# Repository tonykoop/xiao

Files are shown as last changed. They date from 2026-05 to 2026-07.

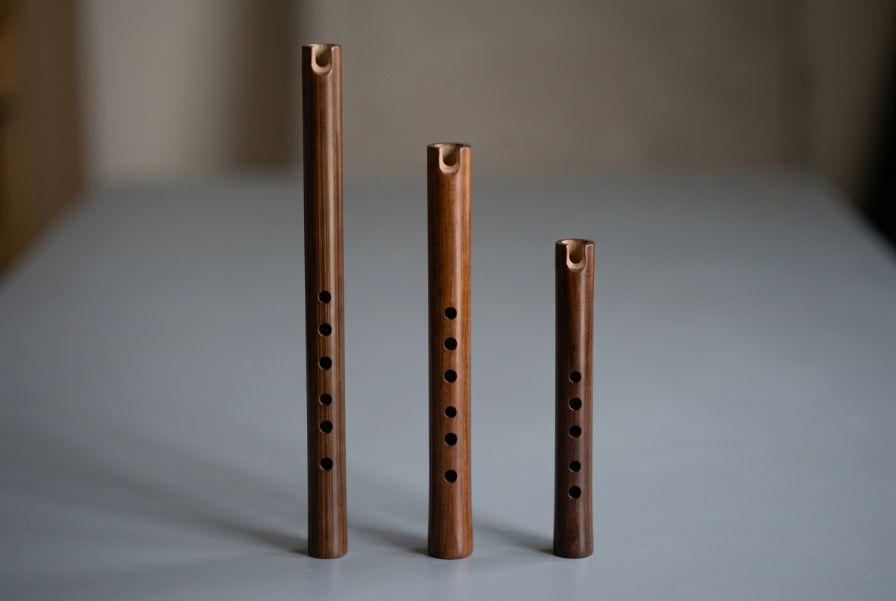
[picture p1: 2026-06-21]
images/family-group.png

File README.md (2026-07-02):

# Xiao Family (箫)

*Engineering documentation and parametric design for the xiao — Chinese end-blown vertical bamboo flute.*

**Build ID:** XIAO-001 · **Variants:** Bei Xiao · Nan Xiao · Qin Xiao · **Scale:** 8-hole chromatic  
**Prototype target:** G Nan Xiao (root D4) · Black walnut · Headstock-driven deep-bore drilling  
Part of the [tonykoop/instrument-maker](https://github.com/tonykoop/instrument-maker) catalogue.

**Status:** L2 V5 build-packet candidate. Bore lengths and tone-hole positions are first-order model predictions — all tuning claims are estimates and must be validated on prototype. All SVGs in `drawings/` are derived previews; Wolfram sources are present but runtime execution is not yet recorded.

---

<!-- hero image placeholder: replace with finished instrument photo after build. Current L2 packet uses generated technical drawings as visual evidence. -->
Xiao bore profile

---

## What this is

The xiao (箫, *xiāo*) is a Chinese end-blown vertical flute with a breathy, dark tone — one of the oldest and most meditative instruments in the Chinese tradition. This repo contains a complete engineering build packet for a CNC-turned wooden prototype across three bore variants:

- **Bei Xiao (北箫)** — Northern style, capped U-notch, larger bore
- **Nan Xiao (南箫)** — Southern style, open bamboo-root end (most common; prototype target)
- **Qin Xiao (琴箫)** — Narrow-bore companion to the guqin zither

The design table covers 26 keys from C4 through D6. The G Nan Xiao (root D4, bore ≈ 22 mm) is the prototype focus.

The key engineering challenge is the 22.5 in straight bore — drilled before turning the exterior, using the headstock-driven technique so the bore axis becomes the lathe datum.

---

## File Map

| File / Folder | Description |
|---|---|
| `xiao-design-table.xlsx` | Parametric design table — all 26 keys × 3 variants |
| `design.md` | Governing acoustic model, hole positions, formulas, assumptions |
| `bom.csv` | Bill of materials |
| `sourcing.csv` | Supplier table |
| `cut-list.csv` | Stock and cut dimensions |
| `validation.csv` | Tuning checkpoints with pass/fail blanks |
| `assembly-manual.md` | Stage-by-stage build instructions |
| `supplier-rfq.md` | RFQ templates for lumber and tooling |
| `visual-bom-brief.md` | Photo/image layout spec for the visual BOM |
| `drawing-brief.md` | Drawing specifications and critical dimensions |
| `risks.md` | Red-team risk register — 12 risks with verification tests |
| `resources.md` | Cultural provenance, acoustic references, open review items |
| `jig-decision.md` | Fixture selection decisions for bore drilling and tone holes |
| `photo-shotlist.md` | Staged photo list for build documentation |
| `drawings/` | Dimensioned SVG drawings (bore profile, tone holes, embouchure, drill setup) |
| `cnc/` | Operation graph, operations.csv, setup-sheet.md |
| `jigs/` | Jig specs — headstock bore carrier, tonehole V-block |
| `wolfram/instrument-model.wl` | Wolfram acoustic model package |
| `cad/` | Parametric OpenSCAD master (`cad/xiao.scad`, bore + tone-hole array) plus SolidWorks CAD placeholder |
| `evolution/` | Evolution-pipeline Stage 0 intake — design intent, revision register, CAD master manifest (Gate A not yet run) |
| `site/index.html` | Build-log static site |
| `images/` | Build photos (populate during build) |
| `data/` | Design intake JSON and CSV |

---

## Build Workflow

```
Design table → Acoustic model → Stock prep → Bore scrap blank (validate) →
Bore tonewood → Turn OD from bore axis → Cut embouchure notch →
Lay out tone holes → Drill tone holes → Voice / tune → Finish → Validate
```

**Critical rule: bore before turning.** The bore axis becomes the lathe datum. Do not turn the exterior first.

---

## Acoustic Model (summary)

- **Model:** Open-open cylindrical pipe — `f = c / (2 · L_eff)`
- **Speed of sound:** 13,504 in/s at 68°F
- **G Nan Xiao prototype:** root D4 = 293.66 Hz → L_eff = 22.99 in → L_bore = 22.47 in
- **End correction (each open end):** δ = 0.6 × r = 0.260 in (embouchure assumed open — TBD)
- **Tone holes:** 8-hole chromatic, offsets +2,+3,+4,+5,+7,+9,+10,+11 semitones from root
- **NAF corrections do NOT apply.** All hole positions first-order until prototype measured.

See `design.md` for full model, all formulas, and the complete hole position table.

---

## Key Drawings

| Drawing | File |
|---|---|
| Bore profile (section view) | `drawings/xiao-bore-profile.svg` |
| Tone hole layout (plan view) | `drawings/xiao-tonehole-layout.svg` |
| Embouchure notch detail | `drawings/xiao-embouchure-detail.svg` |
| Headstock drilling setup | `drawings/xiao-headstock-drill-setup.svg` |

---

## Build Risks (top 3)

1. **RISK-S01 — Bore wander (HIGH):** 22.5 in bore wander risks thin wall or structural failure. Validate on scrap blank first; reject if wander > 0.030 in.
2. **RISK-A01 — Embouchure end correction (HIGH):** Model assumes δ_emb = 0.260 in. Real value unknown until prototype. Leave trim allowance and measure before drilling holes.
3. **RISK-S02 — Embouchure notch cracks (HIGH):** U-notch stress concentration at wall. Radius corners; seal grain immediately. Full register in `risks.md`.

---

## License

[CC BY 4.0](LICENSE) — see LICENSE for details.

---

*Heifer Zephyr instrument catalogue · [tonykoop](https://github.com/tonykoop)*

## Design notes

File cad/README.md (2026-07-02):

# Xiao — CAD Folder

**Status:** `cad/xiao.scad` — parametric OpenSCAD master (bore + tone-hole array only; blowing-edge notch out of scope) — added 2026-07-01. Authority: `pending_measurement`; not fabrication authority until reviewed against a measured prototype. See `mcp-session-log.md` for provenance. SolidWorks parts below remain planned/TBD.

## Planned files

| File | Description | Status |
|---|---|---|
| `xiao-body-nan.SLDPRT` | SolidWorks part — Nan Xiao body (G key) | TBD |
| `xiao-body-bei.SLDPRT` | SolidWorks part — Bei Xiao body | TBD |
| `xiao-body-qin.SLDPRT` | SolidWorks part — Qin Xiao body | TBD |
| `xiao-foot-plug.SLDPRT` | Foot plug part | TBD |
| `xiao-assembly.SLDASM` | Full assembly with plug | TBD |
| `sw-design-table.xlsx` | SolidWorks design table generated from xiao-design-table.xlsx | TBD |

## Workflow

1. Generate SW design table: `python3 scripts/generate_sw_design_table.py . --output cad/sw-design-table.xlsx --part-name XIAO-001_NanXiao`
2. Create SolidWorks part from bore and OD dimensions in design.md
3. Drive all dimensions from the design table (bore ID, OD, wall, total length, hole positions)
4. Export STEP/STL for reference if needed

See `references/solidworks-integration.md` for Tony's SolidWorks workflow conventions.

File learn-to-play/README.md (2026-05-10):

# learn-to-play / Xiao (D)

Starter songbook for the **D-tuned xiao** (洞箫) from the [`xiao`](https://github.com/tonykoop/xiao) build packet. Generated by the [`sheet-music`](https://github.com/tonykoop/sheet-music) skill.

The xiao is a vertical end-blown bamboo flute. The tone is breathy and deep; it favours slow, expressive playing.

Range: **D4 – D6** (two octaves). 6 finger holes + 1 thumb hole.

## Folder map
| Folder | Contents |
|---|---|
| `00-warmup-scales/` | D pentatonic range walk, interval study, vibrato exercise |
| `01-easy/` | Three classic Chinese traditional melodies |
| `02-intermediate/` | Two longer pieces with wider range |
| `03-original/` | *Dawn Reed Song* — Heifer Zephyr original |
| `fingering-charts.svg` | D major and D pentatonic fingering chart, D4–D6 |

## Repertoire

### 01-easy
| Tune | Tradition |
|---|---|
| Mo Li Hua (Jasmine Flower) | Trad Chinese folk song (pre-1900) |
| Xiao He Cai Lian (Picking Lotus) | Trad Chinese (Tang Dynasty tradition) |
| Hotaru Koi (Come Firefly) | Trad Japanese folk (pre-1900) |

### 02-intermediate
| Tune | Tradition |
|---|---|
| Gao Shan Qing (High Mountain Trail) | Trad Taiwanese / Hokkien (pre-1929) |
| Feng Yang Hua Gu (Flower Drum Song) | Trad Chinese (Ming Dynasty origin) |

### 03-original
**Dawn Reed Song** — 24-bar through-composed, D minor pentatonic, ♩=52.

## Notes on xiao notation
Standard staff notation uses concert pitch. The xiao has a low, dark tone; play the written notes
one octave lower than a flute reading the same score (an octave transposing instrument in practice,
though not formally). ABC files here are written for the player's reading convenience.

## License
Arrangements MIT-licensed by Tony Koop / Heifer Zephyr. Traditional tunes: PD.

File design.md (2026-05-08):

# Xiao Family — Design Document

**Instrument:** Xiao (箫) — Chinese end-blown vertical bamboo flute  
**Family variants:** Bei Xiao (北箫) · Nan Xiao (南箫) · Qin Xiao (琴箫)  
**Scale:** 8-hole chromatic  
**Build ID:** XIAO-001  
**Packet version:** v4.3 root-mode  
**Date:** 2026-05-08  
**Status:** First-order acoustic model. Tuning claims are estimates until prototype measured.

---

## 1. Design Intent

The xiao is one of the oldest Chinese wind instruments — an end-blown, notched-embouchure flute with a characteristically dark, breathy tone. This design packet targets a **G Nan Xiao** (root D4, bore ≈ 0.866 in / 22 mm) as the prototype instrument, with the parametric design table covering 26 keys and all three bore variants. The priority challenges are:

- Long-bore cylindrical drilling (≥ 22 in) without wander
- Accurate tone-hole placement from a first-order acoustic model, with tuning trim allowance baked in
- Embouchure geometry (U-notch vs V-notch) and its effect on attack, intonation, and octave response
- End corrections: both ends treated as open terminations (first-order); embouchure end correction is an assumption pending prototype measurement

CNC production is intended for wooden prototypes; bamboo and lacquered-bore variants are noted as material alternatives.

---

## 2. Governing Acoustic Model

### 2.1 Model choice

The xiao is an **open-open cylindrical pipe** (open at embouchure end, open at foot). Use the open-open pipe model:

```
f = c / (2 · L_eff)
L_eff = c / (2 · f)
```

- `c` = speed of sound = 331.3 × √(1 + T_C / 273.15) m/s  
  At 68°F (20°C): **c = 343.0 m/s = 13,504 in/s**

**Do not apply NAF K2 corrections here.** Those corrections are derived from Tony's NAF bore-diameter data and do not apply to the xiao's different bore range, embouchure geometry, or playing technique. Mark all first-order predictions as estimates; add measured corrections to validation.csv after prototype testing.

### 2.2 End corrections

Each open termination adds approximately 0.6 × radius to the effective acoustic length:

```
δ_end ≈ 0.6 · r    (Levine-Schwinger approximation)
```

For an open-open pipe with two open ends:

```
L_eff = L_bore + 2 · δ_end = L_bore + 1.2 · r
```

**Embouchure-end assumption:** The U-notch embouchure is treated as an open end in this first-order model (δ_emb ≈ 0.6·r). In practice, the notch geometry, player lip coverage, and jet angle all modulate the effective length. Expect the embouchure end correction to require empirical refinement on the prototype. Flag this row in validation.csv.

**Foot-end correction:** Standard open-end correction applies at the foot (δ_foot = 0.6·r).

### 2.3 Prototype target — G Nan Xiao

| Parameter | Value | Source |
|---|---|---|
| Xiao key name | G (四孔 = G4) | Naming convention: 4th hole |
| Root note (all holes closed) | D4 | Key − 5 semitones |
| Root frequency | 293.66 Hz | f = 440 × 2^((62−69)/12) |
| Speed of sound | 13,504 in/s | 68°F, 0% RH (shop estimate) |
| **L_eff (acoustic length)** | **22.99 in** | c / (2 · 293.66) |
| Bore ID | 0.866 in | Nan Xiao design table |
| Bore radius | 0.433 in | Bore ID / 2 |
| End correction (each end) | 0.260 in | 0.6 × 0.433 |
| Total end correction | 0.520 in | 2 × δ_end |
| **L_bore (physical bore)** | **22.47 in** | L_eff − 0.520 |
| Wall thickness | 0.236 in | Design table |
| OD (bore + 2·wall) | 1.338 in | Bore + 2 × wall |
| Mouthpiece section length | 2.5 in | Design table (Nan Xiao) |
| **Total blank length** | **~25.5 in** | L_bore + mouthpiece + trim |

> **⚠ FIRST-ORDER ESTIMATE.** L_bore = 22.47 in is the model prediction with assumed end corrections. Add +0.25 in trim allowance to the blank. Final length determined by tuning measurement on the prototype.

### 2.4 Tone-hole placement (first-order)

Acoustic length method (open-open pipe, Benade first-order approximation):

```
d_from_foot(hole_n) = L_eff × (f_root / f_hole_n)
```

This gives the distance from the foot-end opening to where each tone hole's center should ideally be placed for a lossless open termination at that hole. Real-world corrections for finite hole size, undercutting, and adjacent-hole interaction are applied empirically during voicing.

**G Nan Xiao — 8 tone holes (first-order):**

| Hole | Finger | Note | MIDI | Freq (Hz) | Dist from foot (in) | Dist from foot (mm) |
|---|---|---|---|---|---|---|
| 1 | RH pinky | E4 | 64 | 329.63 | 20.48 | 520 |
| 2 | RH ring | F4 | 65 | 349.23 | 19.33 | 491 |
| 3 | RH middle | Gb4 | 66 | 369.99 | 18.25 | 464 |
| 4 | RH index | G4 | 67 | 392.00 | 17.22 | 437 |
| 5 | LH ring | A4 | 69 | 440.00 | 15.34 | 390 |
| 6 | LH middle | B4 | 71 | 493.88 | 13.67 | 347 |
| 7 | LH index | C5 | 72 | 523.25 | 12.90 | 328 |
| 8 | LH thumb | Db5 | 73 | 554.37 | 12.18 | 309 |

> **⚠ FIRST-ORDER ONLY.** These distances will shift in practice. Drill holes 1–2 mm closer to the foot than predicted (under-length tuning margin), then reposition by undercutting. Do not finalize positions without prototype measurement.

### 2.5 Scale offsets (xiao 8-hole chromatic)

From acoustic-models.md — verified against design table:

```
+2, +3, +4, +5, +7, +9, +10, +11 semitones from root
```

Notes +1, +6, +8 require cross-fingering or half-holing. Second octave by overblowing (overblow ratio ≈ 2:1 for cylindrical open pipe).

### 2.6 Naming convention

> **"G xiao"** means hole 4 produces G. Root (all holes closed) = G − 5 semitones = D.  
> Design table column: Root Note = D4 → Xiao Key Name = G4.

---

## 3. Bore Variants

Three bore families are covered in the design table. Prototype is **Nan Xiao**.

| Variant | Bore type | Bore ID range | Wall | Mouthpiece | Character |
|---|---|---|---|---|---|
| Bei Xiao (北箫) | Capped U-notch | 0.472–0.787 in | Proportional | 2.0 in | Northern; fuller tone, larger bore |
| Nan Xiao (南箫) | Open (bamboo root end) | 0.630–0.984 in | Proportional | 2.5 in | Southern; warm, breathy; most common |
| Qin Xiao (琴箫) | Capped U-notch (narrow) | 0.315–0.630 in | Proportional | 3.0 in | Narrow bore; refined tone for guqin pairing |

Blank width/thickness cells are marked TBD in the design table — to be filled once stock form (round rod, split-blank, or bamboo) is confirmed.

---

## 4. Material Assumptions

| Parameter | Prototype | Note |
|---|---|---|
| Body material | Black walnut or cherry | CNC-machinable hardwood. Bamboo (madake/zizhu) for traditional build |
| Bore treatment | TBD | Linseed oil, lacquer, or shellac; internal lacquer stabilizes bore and affects tuning |
| Stock form | Round rod or split-blank | See jig-decision.md for drilling method selection |
| Finish | Natural oil + wax | Avoid thick varnish on bore |

---

## 5. Key Assumptions & Open Questions

| Item | Assumption | Status |
|---|---|---|
| Embouchure end correction | 0.6·r (same as foot) | **TBD — measure on prototype** |
| Bore taper | Zero (cylindrical) | Bamboo is slightly tapered; wooden version is truly cylindrical |
| Hole diameter | TBD (traditional: ~8–10 mm for front holes) | Affects cutoff frequency and playability |
| Hole undercutting | TBD | Cross-cut and undercut during voicing |
| Internal lacquer effect | Assumed negligible | Lacquer shifts effective bore diameter; validate |
| Temperature at play | 68°F / 20°C | Tune at 68°F; note 1 cent/°F sensitivity |
| Breath pressure | Assumed constant | Overblowing model: pressure ratio ≈ 4:1 to 6:1 for second octave |

---

## 6. Parametric Formulas

All formulas should be reproduced parametrically in `xiao-design-table.xlsx`:

```
c = 13504 * SQRT(1 + T_F/491.67)          " in/s, T_F in Fahrenheit
f_root = 440 * 2^((MIDI_root - 69) / 12)  " root frequency
L_eff = c / (2 * f_root)                   " acoustic length, in
delta_end = 0.6 * (bore_ID / 2)            " end correction per end, in
L_bore = L_eff - 2 * delta_end             " physical bore length, in
dist_from_foot(n) = L_eff * (f_root / f_hole_n)  " tone hole position, in
f_hole_n = 440 * 2^((MIDI_root + offset_n - 69) / 12)  " hole frequency
```

Offsets: +2, +3, +4, +5, +7, +9, +10, +11 (holes 1–8).

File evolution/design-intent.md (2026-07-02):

# Design Intent — xiao rev A

- Master CAD: `cad/xiao.scad` (sha256: 3832be6631ce64d141e368377fbe873fe25e27d0db50bf8b6a6dd54874659363), driven by `xiao-design-table.xlsx` (sha256: 17c8b5783f117235e83f1da46e28202ae674b4700645ce71d5cdee196199d32a)
- Function: End-blown Chinese vertical bamboo flute (箫). The G Nan Xiao prototype (root D4, open-open cylindrical bore) is bored straight through a hardwood blank before the exterior is turned (bore axis = lathe datum), then cut with a U-notch embouchure at the top and 8 tone holes (7 front + 1 back thumb) drilled and voiced to a first-order acoustic model. Played near-vertical; breath jet against the notch edge excites the open-open pipe resonance. See design.md and README.md "What this is" / "Acoustic Model".
- Environment: hand-held wind instrument; breath moisture enters the bore during play, so bore finish and material stability (checking, cracking) matter. No sustained structural load beyond normal handling.
- Target qty: 1 (prototype). Deadline: TBD. Budget/unit ceiling: TBD.

## Critical dimensions (carry tolerances)

| Feature | Nominal | Tolerance | Why critical | Source |
| --- | --- | --- | --- | --- |
| Bore ID | 0.866 in | reject scrap-blank wander > 0.030 in (RISK-S01) | sets L_bore and all hole positions | design.md section 2.3 (worked Nan Xiao table); flagged discrepancy vs xiao-design-table.xlsx row16 col E = 0.984 in — see cad/xiao.scad header |
| Physical bore length (L_bore) | 22.47 in | +0.25 in trim allowance before final tuning cut | sets fundamental (D4 = 293.66 Hz) | design.md section 2.3, formula L_eff - 2*delta_end |
| Wall thickness | 0.236 in | min 0.118 in per RISK-S01 (Qin Xiao floor) | structural integrity of 22.5 in bore | design.md section 2.3; flagged discrepancy vs xlsx row17 col E = 0.276 in |
| Tone-hole positions (holes 1-8, dist. from foot) | 20.48 / 19.33 / 18.25 / 17.22 / 15.34 / 13.67 / 12.90 / 12.18 in | drill under-length 1-2 mm toward foot, correct by undercutting (measurement_required) | intonation of 8-hole chromatic scale | design.md section 2.4 (first-order acoustic-length method); reproduced by formula in cad/xiao.scad, exact match verified via OpenSCAD echo |
| Hole diameter | 0.354 in (9 mm) | TBD — affects cutoff frequency and playability | voicing | design.md section 5 "Key Assumptions" — explicitly TBD, traditional range ~8-10mm; used here as a documented ASSUMPTION, not a design-table value |
| Embouchure end correction | 0.260 in (0.6*r), applied as open-end assumption | TBD — measure on prototype (RISK-A01) | fundamental frequency accuracy | design.md section 2.2/2.3; NOT modeled as cut geometry in cad/xiao.scad (blowing edge out of scope) |
| Mouthpiece stock length | 2.5 in | n/a (uncut stock allowance) | leaves material for embouchure notch carving | design.md section 2.3 / xiao-design-table.xlsx row20 col E (both sources agree) |

## Incidental (free for DFM)

- Exterior turning profile/taper of the body (beyond the bore-driven OD), decorative wrap placement, foot-plug cosmetic shaping, finish sheen.

## Must-nots (DFM may never violate)

- Never turn the exterior before boring — the bore axis is the lathe datum (design.md "Build Workflow"; "Critical rule: bore before turning").
- Never exceed 0.030 in bore wander on the scrap-blank validation test before committing to the tonewood blank (RISK-S01, risks.md).
- Never cut the embouchure notch wider than the bore diameter (~12 mm max) or with square (non-radiused) corners — stress-concentration crack risk at the thin mouthpiece wall (RISK-S02, risks.md).
- Never drill tone holes before the embouchure cut and fundamental-frequency check — δ_emb must be measured and L_bore reconciled first, or all hole positions will be systematically off (RISK-A01, risks.md).
- Never apply bore finish after tone holes are drilled without masking — finish pooling in holes sharpens notes unpredictably (RISK-FF01, risks.md).

## Material intent

- Preferred: black walnut (or cherry) hardwood body blank, kiln-dried (MC <= 8%); bore finish boiled linseed oil or shellac; exterior finish Danish oil or wax. Per bom.csv.
- Acceptable subs: bamboo (madake/zizhu) for a traditional build, per design.md section 4 "Material Assumptions" — not costed in bom.csv.
- Forbidden: none recorded.

## Stage status

Stage 0 intake complete 2026-07-01. Gate A (Alpha shop compile) NOT yet run — no concessions logged, nothing presented as shippable.

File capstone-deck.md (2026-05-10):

# Xiao Family Capstone Deck Outline
## XIAO-001 · G Nan Xiao · v4.3 · 2026-05-08

> Binary .pptx: run `python3 scripts/generate_capstone_docs.py . --title "Xiao Capstone"` when bash is available.

---

# Slide 1 — Title

**Xiao Family (箫)**  
*Chinese End-Blown Vertical Flute — Engineering Documentation*  
Build ID: XIAO-001 · G Nan Xiao prototype · Heifer Zephyr · 2026-05-08

[hero image: finished xiao, vertical, natural light]

---

# Slide 2 — What This Project Is

**One sentence:** A parametric engineering study of the Chinese xiao, producing a CNC-turned wooden prototype of the G Nan Xiao with a 22.5 in deep-bored cylindrical bore, 8-hole chromatic scale, and first-order acoustic validation.

**Intended use:**
- Demonstrate long-bore woodwind design and headstock-driven drilling technique
- Establish baseline acoustic model for three bore variants (Bei/Nan/Qin)
- Populate the Heifer Zephyr instrument catalogue with a new woodwind family

**Design table covers:** 26 keys × 3 variants (Bei / Nan / Qin Xiao)

---

# Slide 3 — File Map

| File | Purpose | Use when |
|---|---|---|
| `xiao-design-table.xlsx` | Parametric design — all keys and variants | All dimensions |
| `design.md` | Acoustic model, formulas, hole positions | Building the physics |
| `assembly-manual.md` | Stage-by-stage build guide | In the shop |
| `cnc/setup-sheet.md` | Operation plan, release checks | Before each operation |
| `jigs/*.md` | Jig specs for bore and tone holes | Fixture setup |
| `drawings/*.svg` | Bore profile, tone holes, embouchure, drill setup | Layout and reference |
| `wolfram/instrument-model.wl` | Wolfram acoustic model package | Physics validation |
| `risks.md` | 12 risks with verification tests | Before cutting material |
| `validation.csv` | Tuning checkpoints | After each voicing pass |
| `site/index.html` | Public build-log site | Sharing with outside makers |

---

# Slide 4 — Build Workflow

```
Stock prep → Bore SCRAP (validate) → Bore tonewood → Turn OD from bore axis
→ Embouchure notch (by ear) → Lay out tone holes → Drill holes
→ Voice / tune (strobe) → Bore finish → Validate → Ship
```

**Critical rule: Bore before turning.** The bore axis is the lathe datum.  
**Critical rule: Scrap blank first.** Bore wander < 0.030 in before touching tonewood.  
**Critical rule: All tuning claims first-order** until prototype measured.

---

# Slide 5 — Acoustic Model

**Governing model:** Open-open cylindrical pipe  
`f = c / (2 · L_eff)` · `L_eff = L_bore + 1.2 · r` (both ends open)

**G Nan Xiao prototype:**

| Parameter | Value | Status |
|---|---|---|
| Root (D4) | 293.66 Hz | Formula |
| L_eff | 22.99 in | Calculated |
| δ_emb | 0.260 in assumed | **TBD — measure on prototype** |
| L_bore | 22.47 in | **FIRST-ORDER ESTIMATE** |
| Bore ID | 0.866 in | Design table |

**Scale:** 8-hole chromatic, offsets +2,+3,+4,+5,+7,+9,+10,+11 from root  
**Key convention:** Xiao key = 4th hole note (G xiao has root D)  
**No NAF corrections** — different embouchure geometry and bore range.

[embed: drawings/xiao-tonehole-layout.svg]

---

# Slide 6 — BOM and Sourcing

| Item | Qty | Cost | Status |
|---|---|---|---|
| Black walnut blank 1.5×1.5×26 in | 1 | $8–15 | TBD |
| Scrap pine/poplar blank | 1 | $3–5 | TBD |
| 1/4 in pilot bit 18 in+ | 1 | $8 | TBD |
| 55/64 in finish bit 18 in+ | 1 | $25–45 | **Order first — lead time 3–5 days** |
| 7/8 in adjustable reamer | 1 | $35 | TBD |
| Bore + exterior finish | 1 set | $9 | Available |
| Tailstock carrier (shop-made) | 1 | $15 | TBD |
| **Total (est.)** | | **~$109** | |

**Lead-time risk:** 55/64 in bit. Order before cutting stock.

---

# Slide 7 — Drawings and CAD

[embed: drawings/xiao-bore-profile.svg] — Bore Profile (DWG-001)  
[embed: drawings/xiao-headstock-drill-setup.svg] — Drill Setup (DWG-004)

| Drawing | Status | File |
|---|---|---|
| Bore profile | ✅ Generated | drawings/xiao-bore-profile.svg |
| Tone hole layout | ✅ Generated | drawings/xiao-tonehole-layout.svg |
| Embouchure detail | ✅ Generated | drawings/xiao-embouchure-detail.svg |
| Drill setup diagram | ✅ Generated | drawings/xiao-headstock-drill-setup.svg |
| SolidWorks body part | ❌ TBD | cad/ |

---

# Slide 8 — CNC / Operation Plan

**Machines:** Wood lathe (bore + turning) · Drill press (tone holes) · Router table (embouchure notch)

**9 operations sequenced** in `cnc/cnc-plan.json` + `cnc/setup-sheet.md`:

OP-01 Stock → OP-02 Bore scrap (**gate**) → OP-03 Bore tonewood → OP-04 Turn OD → OP-05 Notch → OP-06 Layout → OP-07 Drill holes → OP-08 Voice → OP-09 Finish

Each operation has a **release check** — the next OP cannot start until it passes.

---

# Slide 9 — Assembly

**Bore before turning** (bore axis = lathe datum)  
**Headstock-driven drilling:** bit in headstock Jacobs chuck; blank stationary in tailstock carrier  
**Peck drilling:** 0.5 in pecks, retract to clear chips, conservative RPM (500–800)  
**Embouchure notch:** set by ear, not by dimension — bevel angle refined to produce stable edge tone  
**Tone holes:** drilled 1–2 mm toward foot; undercut to tune sharp → flat

See `assembly-manual.md` and `jigs/` for full procedures.

---

# Slide 10 — Validation Plan

| Check | Target | Tolerance | Tool |
|---|---|---|---|
| Bore wander (scrap) | < 0.030 in | — | Calipers |
| Bore diameter | 0.866 in | ± 0.005 in | Telescoping gauge |
| Fundamental (D4) | 293.66 Hz | ± 5 cents | Korg OT-120 / Peterson |
| Embouchure δ (measured) | TBD | — | Back-calculate from f_meas |
| Each tone hole (H1–H8) | See design.md | ± 10 cents | Strobe tuner |
| Overblown octave | 587.33 Hz | ± 15 cents | Strobe tuner |

All measurements at 68°F. Record temperature in validation.csv.

---

# Slide 11 — Open Risks

| Risk | Severity | Status |
|---|---|---|
| RISK-A01: Embouchure δ unknown | HIGH | TBD — measure on blank |
| RISK-S01: Bore wander | HIGH | Mitigated: scrap validation |
| RISK-S02: Notch crack | HIGH | Mitigated: CA seal, radius corners |
| RISK-A03: Bore finish shifts pitch | MEDIUM | Mitigated: apply before voicing |
| RISK-SU01: 55/64 bit lead time | MEDIUM | Order before cutting stock |

Full register: `risks.md` — 12 risks with verification tests.

---

# Slide 12 — Next Actions

- [ ] Order 55/64 in long-series drill bit (lead time risk)
- [ ] Mill or source walnut blank + scrap blank
- [ ] Build tailstock square-stock carrier jig
- [ ] Run scrap bore validation — record wander and bore diameter
- [ ] If scrap passes: bore tonewood
- [ ] Measure fundamental on bored blank before drilling holes
- [ ] Update L_bore in design.md if δ_emb ≠ 0.260 in
- [ ] Drill tone holes and voice
- [ ] Populate validation.csv and images/
- [ ] Generate binary capstone-deck.pptx and print-packet.pdf (when bash available)
- [ ] SolidWorks CAD part from design table

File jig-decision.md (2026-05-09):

# Xiao — Jig Decision Record

**Project:** XIAO-001 · G Nan Xiao  
**Date:** 2026-05-08

This document records jig selection decisions, trade-offs considered, and fixture specifications for the xiao build. Part of the v4.3 public-readiness adjunct set.

---

## Decision 1 — Long-Bore Drilling Method

**Question:** How do we drill a 22.5 in straight bore through a 1.5 in square hardwood blank?

### Options considered

| Method | Description | Pros | Cons |
|---|---|---|---|
| **A. Headstock-driven drilling** | Bit spins in headstock Jacobs chuck; square blank advanced from tailstock vise (selected) | Works with square stock pre-turning; single setup; validated on pan-flute builds | Requires rigid tailstock carrier; long bits whip; scrap validation mandatory |
| B. Split-blank routing | Rip blank in half; CNC-route semicircular channel in each half; re-glue | Precise bore profile; accessible for cleanup | Glue line in bore; registration error risk; seam affects tone |
| C. Drill press with extension | Index blank through drill press; drill from both ends to meet | Simple tooling | Bore wander at junction; difficult to center-match from both ends |
| D. Long-series bit in drill chuck (no lathe) | Freehand long-bit boring | Lowest setup | High wander risk on long bore; not recommended |

**Decision: Method A — Headstock-driven drilling.**

Rationale: The xiao bore is cylindrical (no taper) and must be drilled before turning the OD — the bore axis becomes the datum for all subsequent turning. Method A is the only approach that guarantees the bore and OD share a common axis. The split-blank glue-line risk is unacceptable for a tuned bore instrument. The pan-flute precedent (Uncle Carpenter reference) gives validated setup procedures.

**Fallback:** If bore wander on the scrap blank exceeds 0.030 in with Method A, switch to Method B (split-blank routing with CNC) for the tonewood blank.

---

## Decision 1 — Fixture Specifications

**Tailstock square-stock carrier (shop-made):**

- Material: 3/4 in Baltic birch plywood or MDF, 2 layers laminated
- Channel: Square pocket sized to blank cross-section (1.5 in × 1.5 in + 0.002 in slip fit)
- Anti-rotation: Two side clamps (toggle clamps or hand screws) engaging blank faces
- Alignment: Carrier rides on lathe bed and is shimmed until center of pocket tracks spindle axis (verify with dial indicator)
- Steady rest: Optional — mount between tailstock and headstock for blanks >24 in

**Lathe taper and chuck:**
- Headstock taper: Confirm MT2 or MT3 (lathe-specific — check before ordering chuck)
- Jacobs chuck capacity: Must accept 1/4 in and 55/64 in shanks. Most 5/8 in capacity chucks work for pilot; 1 in capacity chuck needed for finish bit.
- Drill bit shank: Reduce-shank bits acceptable if chuck capacity is insufficient

**Depth stop:**
- Mark finish bore depth on drill shank with tape flag at: 25.0 in from chuck face
- This limits drilling depth and prevents running the chuck into the carrier

---

## Decision 2 — Tone Hole Drilling Jig

**Question:** How do we drill perpendicular tone holes at precise axial positions along a round (post-turning) body?

### Options considered

| Method | Pros | Cons |
|---|---|---|
| **A. V-block + drill press fence (selected)** | Simple; adjustable; works with any diameter | Requires fence indexed to body length |
| B. Laser-cut template sleeve | Accurate if made correctly; reusable | Requires template material and laser time |
| C. Freehand with pilot holes | Fastest | Not accurate enough for ±1 mm tone hole placement |

**Decision: Method A — V-block clamped to drill press fence with length stop.**

**Fixture specification:**
- V-block: Commercial or shop-made, sized for 1.338 in OD body
- Length stop: Adjustable stop clamped to drill press fence. Set stop distance = distance from foot + bore center offset for each hole
- Perpendicularity: V-block aligns bore axis horizontally; drill press provides vertical drill axis — holes are automatically perpendicular to bore
- Sequence: Drill in order from foot toward head (holes 1 → 8), re-indexing stop for each

See `jigs/tonehole-drilling-jig.md` for full fixture setup diagram.

---

## Decision 3 — Embouchure Notch Cutting

**Question:** How do we cut the U-notch with consistent geometry and a clean inner bevel?

### Options considered

| Method | Pros | Cons |
|---|---|---|
| **A. Router bit in drill press or router table (selected)** | Consistent profile; controllable depth | Requires correct bit radius; setup time |
| B. Chisel and mallet (hand cut) | Traditional; flexible | Skill-dependent; hard to reproduce |
| C. CNC router (if body is held in fixture) | Most precise | Requires fixture and CAM setup |

**Decision: Method A — small ball-nose or straight router bit in drill press, followed by hand bevel refinement.**

The router establishes the notch width and initial depth. The inner bevel — the acoustic edge — is refined by hand with a sharp chisel. This is a judgment call that depends on the prototype's tonal response; no fixture can substitute for listening during voicing.

**Notch geometry starting point (TBD — refine by playing):**
- Width: 10–12 mm centered on bore axis
- Depth: ~5 mm below OD surface (intersects bore at upper tangent line)
- Inner bevel: 45° into bore toward foot; sharpen with chisel to a clean edge

---

## Decision 4 — Foot Plug Fit

**Question:** Should the foot plug be fixed (glued) or adjustable?

**Decision: Adjustable (friction fit, no glue) for prototype.**

A sliding foot plug allows ±2–3 mm of acoustic length adjustment, providing a coarse pitch trim of approximately ±8–12 cents. This is useful during prototype tuning before committing to final hole positions. Mark plug insertion depth on body for reproducibility. If a fixed plug is desired for production, glue after final tuning is confirmed.

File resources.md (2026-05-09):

# Xiao — Resources and Provenance

**Project:** XIAO-001 · G Nan Xiao  
**Date:** 2026-05-08

This document records cultural context, acoustic references, design provenance, and learning resources used to inform this packet. It is part of the v4.3 public-readiness adjunct set.

---

## Cultural Provenance

The xiao (箫, also 洞箫 *dòngxiāo*, "cave flute") is one of the oldest and most studied Chinese wind instruments. Its lineage traces to at least the Tang Dynasty (7th–10th century CE) and likely earlier — possibly descended from Qiang ethnic-minority end-blown flutes of western China. The instrument figures prominently in Chinese court music, literati culture, and Daoist ritual practice, where its dark, breathy tone was considered closest to the human voice.

Three main regional and functional variants appear in the design table:

- **Bei Xiao (北箫)** — Northern style; relatively large bore, capped U-notch mouthpiece. Brighter and more projecting than the southern variant.
- **Nan Xiao (南箫)** — Southern style; the most widely played variant; open bamboo-root end, slightly larger bore, sweet and breathy character. The G Nan Xiao (root D4) is the most common teaching instrument.
- **Qin Xiao (琴箫)** — Guqin companion; narrow bore, longer mouthpiece section, refined and intimate tone used in chamber settings alongside the guqin (古琴) zither.

The xiao naming convention (key = 4th hole note) diverges from Western flute convention and from NAF convention. This is captured in the design table header and in design.md §2.6.

**Cultural review note:** This packet targets a **CNC-wood prototype** of a traditionally bamboo instrument. The design does not claim to reproduce the tonal characteristics of a historically sourced bamboo instrument. It is an engineering study using the xiao's acoustic geometry as the subject. Any public-facing documentation should make this distinction clearly.

---

## Acoustic References

| Reference | Notes |
|---|---|
| Benade, A.H. — *Fundamentals of Musical Acoustics* (1990) | Open-pipe model, tone-hole cutoff frequency, end-correction theory |
| Fletcher & Rossing — *The Physics of Musical Instruments* (2nd ed, 1998) | Woodwind bore acoustics, jet–edge interaction at the embouchure |
| Nederveen, C.J. — *Acoustical Aspects of Woodwind Instruments* (rev. 1998) | Tone hole lattice, effective length corrections, conical vs cylindrical bore |
| Wolfe, J. — UNSW Musical Acoustics (online) | Free online calculator for flute acoustics; useful for end-correction crosscheck |
| Yoshikawa, S. — papers on shakuhachi acoustics (J. Acoust. Soc. Am.) | Edge-tone and embouchure jet physics relevant to notch-type embouchures |

Recommended cross-check: [UNSW Flute Acoustics](https://www.phys.unsw.edu.au/music/flute/) — the open cylindrical flute calculator provides an independent estimate of hole positions that can validate the first-order model in design.md.

---

## Design Provenance

| Item | Source | Location |
|---|---|---|
| Bore dimensions (all 3 variants) | xiao-design-table.xlsx | `xiao-design-table.xlsx` |
| Open-pipe acoustic model | instrument-maker-v4 acoustic-models.md | Skill reference |
| Headstock drilling technique | Uncle Carpenter pan-flute video (YouTube) | `references/techniques/headstock-driven-deep-bore-drilling.md` |
| Tone-hole scale offsets | acoustic-models.md — Xiao 8-Hole Chromatic row | +2,+3,+4,+5,+7,+9,+10,+11 |
| Naming convention | acoustic-models.md — Naming conventions | Key = 4th hole note |
| Wolfram notebook spec | xiao-design-table.xlsx §5–6 | Embedded in design table |

---

## Learning Resources

| Resource | URL / Location | Notes |
|---|---|---|
| UNSW Musical Acoustics — Flute | https://www.phys.unsw.edu.au/music/flute/ | Open-pipe hole position calculator |
| Chinese Music Society of North America | https://www.chinesemusic.net | Cultural context, performance practice |
| Flute acoustics intro (Joe Wolfe) | https://www.phys.unsw.edu.au/jw/fluteacoustics.html | Accessible introduction to woodwind physics |
| Xiao tutorial (YouTube — various) | Search: '箫 教学' or 'xiao tutorial' | Embouchure formation, hand position |
| instrument-maker repo | https://github.com/tonykoop/instrument-maker | Parent skill and catalog |
| Heifer Zephyr instrument catalog | GitHub — tonykoop | Cross-instrument family reference |

---

## Open Review Items

- [ ] **Bamboo vs wood tuning delta:** Internal lacquer on bamboo xiao shrinks effective bore and shifts pitch flat. Quantify this for the wooden prototype by applying BLO and re-measuring. Add correction to validation.csv.
- [ ] **Regional tuning pitch:** Traditional Chinese pitch may not be A=440 Hz. Some professional xiao are tuned to A=442. Confirm target pitch standard before final voicing.
- [ ] **Makerspae cultural signage:** If the xiao is displayed or demonstrated at Maker Nexus, include a brief provenance card explaining the instrument's origin and the engineering/materials divergence from traditional bamboo.

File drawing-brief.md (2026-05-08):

# Xiao — Drawing Brief

**Project:** XIAO-001 · G Nan Xiao  
**Date:** 2026-05-08  
**Drawing standard:** Blueprint quality (Strat blueprint reference — see drawing-and-visualization.md)  
**Units:** Inches primary, mm in parentheses

---

## Drawings Required

### DWG-001 — Bore Profile (Side View)
**File:** `drawings/xiao-bore-profile.svg`  
**Status:** Generated (first-order)  
**Contents:**
- Full-length side view of the xiao body, section cut on centerline
- Bore ID labeled: 0.866 in (22 mm)
- OD labeled: 1.338 in (34 mm)
- Wall thickness: 0.236 in (6 mm)
- Total body length: 25.5 in (648 mm) nominal
- Bore length: 22.47 in (571 mm) — labeled "FIRST-ORDER ESTIMATE"
- Mouthpiece section: 2.5 in from head end
- Foot end: open, with plug location noted
- Datum: foot-end open face = 0.000

### DWG-002 — Tone Hole Layout (Plan View)
**File:** `drawings/xiao-tonehole-layout.svg`  
**Status:** Generated (first-order)  
**Contents:**
- Unwrapped top surface of xiao body (front-hole side)
- All 8 holes with centers marked, distances from foot labeled
- Hole numbers and notes labeled
- Holes shown as circles (diameter TBD — use 8 mm / 0.315 in as placeholder)
- TBD callout on all hole positions: "FIRST-ORDER — verify on prototype"

### DWG-003 — Embouchure Detail
**File:** `drawings/xiao-embouchure-detail.svg`  
**Status:** Generated (schematic)  
**Contents:**
- Enlarged cross-section of mouthpiece end (2× scale)
- U-notch geometry: width TBD (~11 mm), depth TBD (~5 mm)
- Inner bevel angle: ~45° (starting point)
- Lip contact zone indicated
- Player's breath direction arrow (airstream direction)
- Bore axis shown in phantom line

### DWG-004 — Headstock Drilling Setup (Jig Diagram)
**File:** `drawings/xiao-headstock-drill-setup.svg`  
**Status:** Schematic placeholder  
**Contents:**
- Lathe bed elevation view
- Headstock with Jacobs chuck and long drill bit
- Tailstock with square-stock carrier / V-block
- Blank clamped in carrier, stationary
- Anti-rotation clamps labeled
- Drill peck depth annotation
- Safety zone callout (no-hands region at chuck)

---

## Critical Dimensions (shop reference)

| Dimension | Value | Status |
|---|---|---|
| Bore ID | 0.866 in (22.0 mm) | Design table |
| OD | 1.338 in (34.0 mm) | Derived |
| Wall thickness | 0.236 in (6.0 mm) | Design table |
| Total body length | 25.5 in (648 mm) | Nominal — add trim allowance |
| Bore length | 22.47 in (571 mm) | FIRST-ORDER ESTIMATE |
| L_eff (acoustic) | 22.99 in (584 mm) | Calculated |
| Hole 1 from foot | 20.48 in (520 mm) | FIRST-ORDER ESTIMATE |
| Hole 4 from foot | 17.22 in (437 mm) | FIRST-ORDER ESTIMATE |
| Hole 8 from foot | 12.18 in (309 mm) | FIRST-ORDER ESTIMATE |
| Notch width | ~11 mm | TBD — prototype |
| Notch depth | ~5 mm | TBD — prototype |

---

## CAD Status

| File | Status | Notes |
|---|---|---|
| `cad/xiao-body.SLDPRT` | TBD | SolidWorks part — not yet created |
| `cad/xiao-design-table.xlsx` | TBD | SW design table from xiao-design-table.xlsx |
| `cad/xiao-assembly.SLDASM` | TBD | Assembly with foot plug |

See `references/solidworks-integration.md` for design table workflow.

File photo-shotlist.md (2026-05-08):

# Xiao — Photo Shot List

**Project:** XIAO-001 · G Nan Xiao  
**Date:** 2026-05-08  
**Pipeline:** See `docs/photo-pipeline.md` in instrument-maker repo for naming and storage conventions.

---

## Phase 1 — Stock and Setup

- [ ] Raw walnut blank — square stock, end grain visible
- [ ] Scrap blank next to tonewood blank (side by side for scale)
- [ ] Headstock Jacobs chuck with pilot bit installed, pre-drilling
- [ ] Tailstock carrier / V-block fixture, blank inserted (before first peck)

## Phase 2 — Boring

- [ ] Pilot bore entry, chip clearing mid-sequence
- [ ] Measuring bore entry with telescoping gauge + calipers
- [ ] Finish bit (55/64) installed in headstock
- [ ] Bore complete — light through bore (overhead photo showing bore as a dark circle)
- [ ] Bore wander measurement on scrap blank (exit vs entry)

## Phase 3 — Turning

- [ ] Blank mounted between centers (bore plug at tailstock end)
- [ ] OD turning — lathe in action, continuous spiral chip
- [ ] Finished cylinder: smooth OD, uniform diameter
- [ ] Caliper measurement of OD at mid-bore

## Phase 4 — Embouchure

- [ ] Notch layout marked on mouthpiece end (pencil line)
- [ ] Notch roughed with router bit or chisel
- [ ] Inner bevel completed — close-up of bevel edge
- [ ] First sound: researcher blowing test (documentary / process shot)

## Phase 5 — Tone Holes

- [ ] Hole positions marked with pencil and calipers
- [ ] Tonehole jig clamped around body, ready to drill
- [ ] First hole being drilled (action shot)
- [ ] All 8 holes drilled, pre-voicing
- [ ] Strobe tuner reading during voicing (document cents error)

## Phase 6 — Finishing

- [ ] Bore finish application (cloth strip technique)
- [ ] Exterior oil being wiped on
- [ ] Optional: decorative wrap being applied
- [ ] Foot plug fitted

## Hero Shots (Final Instrument)

- [ ] Vertical portrait, full length, natural light — **primary hero image**
- [ ] Embouchure close-up (notch, inner bevel, playing position)
- [ ] Tone holes close-up — all 8, even spacing visible
- [ ] Foot end with plug
- [ ] Player-perspective (looking down from mouthpiece position)
- [ ] Side-by-side with bei xiao and qin xiao if multiple variants built

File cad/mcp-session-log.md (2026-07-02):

# CAD / MCP Session Log — xiao

No external MCP or creative-tool sessions have produced artifacts in this packet as of 2026-05-29.
All SVGs in `drawings/` were generated from the design-table by prior sprint agents without an
interactive OpenSCAD MCP, Blender MCP, Illustrator MCP, or image-gen session.

When an OpenSCAD MCP, Blender MCP, or image-gen session produces or modifies a repo artifact,
add a row to the table below before committing that artifact.

| session_id | tool | input_authority | outputs | role | authority_result | review_status | notes |
|---|---|---|---|---|---|---|---|
| fable-v5-refresh-2026-07-01 | claude-code (Fable 5) | xiao-design-table.xlsx, design.md | bom.csv, sourcing.csv, cut-list.csv, validation.csv | packet_refresh | fabrication | self_checked | V5 refresh pass; tabular packet data reviewed against design table |
| fable-v5-refresh-2026-07-01 | claude-code (Fable 5) + OpenSCAD CLI | xiao-design-table.xlsx, design.md | cad/xiao.scad | cad_authoring | pending_measurement | self_checked | New parametric master authored (no prior cad/xiao.scad existed). Bore + tone-hole array scoped only; blowing-edge notch explicitly out of scope. Hole positions and L_eff/L_bore reproduced by formula from design.md 2.3/2.4/2.6 and verified against design.md's published table via OpenSCAD echo output (exact match). Flags a bore_id/wall_thickness discrepancy between design.md's worked table (0.866 in / 0.236 in) and xiao-design-table.xlsx row16/17 column E (0.984 in / 0.276 in) — used design.md's internally-consistent values, discrepancy documented in cad/xiao.scad header for reconciliation. OpenSCAD render check: pass (`openscad -o /tmp/xiao-check.stl cad/xiao.scad`, exit 0). |

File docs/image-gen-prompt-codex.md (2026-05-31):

# Image Generation Prompt

Concept image only; not fabrication authority. Do not include cut-ready dimensions, hole locations, or toolpaths.

## Hero Prompt

Photorealistic 3/4 studio product photograph of the XIAO-001 G Nan Xiao wooden prototype: a long vertical end-blown flute in black walnut or cherry with a straight cylindrical bore, natural oil-and-wax finish, eight chromatic tone holes including thumb hole implied by angle, and a clean U-notch embouchure at the top. The body should be slim, dark, and breathy in character, with understated workshop precision, realistic 22.5-inch long-bore scale cues, clean neutral background, soft directional studio lighting, high detail, 50mm lens look.

## In-Context Prompt

Photorealistic scene of the xiao being played vertically in a quiet woodshop or small chamber-music room, player hands covering the front holes naturally, lower lip near the U-notch, headstock deep-bore drilling jig and tone-hole V-block resting on a bench in the background. Natural window light, calm meditative mood, and a Western wooden prototype framing that respects Chinese xiao tradition without claiming traditional bamboo authenticity.

## Detail / Macro Prompt

Macro photorealistic close-up of the xiao embouchure end: clean U-notch cut into black walnut or cherry, sealed end grain, smooth bore opening, subtle oil-wax sheen, and the first tone hole blurred down the long cylindrical body. Use shallow depth of field, crisp wood grain, and no measurement annotations.

## Negative / Avoid

No text, no watermarks, no brand logos, no extra limbs, anatomically plausible hands if shown, no bamboo-root exaggeration for the wooden prototype, no NAF-style block, no hole-location diagrams, no dimensions, no toolpaths.

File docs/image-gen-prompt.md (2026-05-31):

# Image-Gen Prompts

Concept image only; not fabrication authority. Do not include cut-ready dimensions, hole locations, or toolpaths.

## Hero Prompt

A single finished xiao — a Chinese end-blown vertical bamboo flute — standing upright as a long slender cylindrical tube roughly two feet tall, photographed as a clean studio product shot. The body is a smooth straight cylinder of warm dark-grained hardwood (black walnut, lightly figured, natural oil-and-wax finish) with a satin sheen, true cylindrical bore implied by the even wall and open foot end. The defining feature at the top is the end-blown embouchure: a crisp U-shaped notch cut into the rim of the mouthpiece end with a clean inner bevel, the way the player blows across rather than into a fipple. Down the front face march a vertical column of round tone holes (eight finger holes plus a thumb hole on the back), evenly spaced, dark open circles against the wood. The open foot end shows the round mouth of the bore. Neutral seamless light-gray studio background, soft directional studio light from upper left, gentle falloff, 3/4 product-photography angle, ~50mm lens, shallow but controlled depth of field, realistic scale cues, high detail, photorealistic, no text labels.

## In-Context Prompt

A xiao resting in a quiet woodworker's studio, propped vertically against a workbench of pale wood beside a coil of decorative wrapping thread and a small dish of finishing oil, soft natural window light raking from the side, motes of sawdust in the air. The dark walnut body glows warm against the muted workshop tones; the end-blown notch and the vertical line of tone holes catch the light. Environmental storytelling of a handmade instrument near completion, shallow depth of field with the flute sharp and the background softly blurred, calm contemplative mood, concept visualization only.

## Detail Prompt

Macro close-up of the xiao's signature feature — the end-blown U-notch embouchure at the top of the mouthpiece. Fill the frame with the rim of the dark walnut tube: the clean U-shaped notch carved into the edge, the smooth inner bevel sloping into the bore, the open dark circle of the cylindrical bore beyond, and the satin grain of the hardwood. Raking low-angle light to emphasize the bevel geometry, the cut edge, and the wood figure. Extremely high detail, tactile material texture, no measurements.

## Negative / Avoid

No text, logos, watermarks, fake maker marks, brand names, or carved characters; no dimension callouts or measurement lines; no fipple/whistle mouthpiece, no recorder windway, no side-blown transverse hole, no keys or metal mechanism; anatomically plausible hands if a player is shown.

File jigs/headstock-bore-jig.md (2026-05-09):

# Jig: Headstock-Driven Bore — Tailstock Square-Stock Carrier

**Project:** XIAO-001 · G Nan Xiao  
**Operation:** OP-02, OP-03  
**Decision basis:** jig-decision.md — Decision 1

---

## Purpose

Hold the xiao blank stationary (non-rotating) in the tailstock position while the lathe headstock spins the long drill bit. The tailstock quill advances the blank into the spinning bit. See `references/techniques/headstock-driven-deep-bore-drilling.md` for full technique details.

## Materials

- (2×) 3/4 in Baltic birch plywood or MDF, 12 in × 6 in
- (4×) 1/4 in carriage bolts + wing nuts (for laminating and clamping)
- (2×) toggle clamps (De-Sta-Co 225-U or equivalent) — anti-rotation
- (1×) Lathe tool-rest base or flat sled that rides the lathe bed ways

## Fabrication

1. Cut two plywood panels, laminate to 1.5 in total thickness.
2. Mark the center of the panel face. Locate spindle-axis height (measure from lathe bed to spindle centerline).
3. Cut a square pocket centered at spindle-axis height: 1.5 in × 1.5 in + 0.003 in slip clearance.
4. Mount toggle clamps on left and right faces of the pocket, positioned to engage the blank faces.
5. Attach the assembly to a sled that slides along the lathe bed ways without rocking.
6. Verify alignment: insert a straight rod through the pocket; the rod should run parallel to spindle axis within 0.010 in over 12 in.

## Setup Checklist

- [ ] Carrier mounted, sled verified square to lathe bed
- [ ] Spindle-axis alignment checked with dial indicator (center of pocket within 0.010 in of spindle axis)
- [ ] Toggle clamps open and ready
- [ ] Scrap blank center-punched and inserted in carrier
- [ ] Anti-rotation clamps engaged — verify blank cannot rotate
- [ ] Pilot bit mounted in headstock chuck; runout < 0.005 in at tip
- [ ] Depth stop (tape flag) set at 25 in from chuck face

## Photo reference

Photograph the carrier setup before each drilling session and save to `images/headstock-setup.jpg`.

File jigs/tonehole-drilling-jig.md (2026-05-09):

# Jig: Tone Hole Drilling — V-Block + Length Stop

**Project:** XIAO-001 · G Nan Xiao  
**Operation:** OP-07  
**Decision basis:** jig-decision.md — Decision 2

---

## Purpose

Hold the round xiao body (OD 1.338 in) perpendicular to the drill press spindle while indexing each hole precisely along the body length from the foot datum.

## Materials

- (1×) Commercial V-block, sized for 1.5 in OD or larger (common machinist V-block works)
- (1×) Clamp to hold V-block to drill press table
- (1×) Length-stop — adjustable stop clamped to drill press fence
- (1×) Steel rule or calipers for stop setting

## Setup Procedure

1. Mount V-block on drill press table; align V groove parallel to drill press column.
2. Clamp the foot stop at the hole-1 distance from drill press spindle centerline (20.48 in from foot face — minus 1–2 mm tuning margin → set at 20.30 in).
3. Place body in V-block, foot end against the stop.
4. Verify body is horizontal and drill bit is perpendicular to body surface (no tilt).
5. Drill hole 1: pilot first, then finish size.
6. Re-set stop for hole 2 (stop distance = 19.15 in, etc. — see operations.csv).
7. Repeat for all 8 holes.

## Stop Distances (with −1 mm tuning margin applied)

| Hole | Note | Model dist (in) | Stop dist (in) |
|---|---|---|---|
| H1 | E4 | 20.48 | 20.44 |
| H2 | F4 | 19.33 | 19.29 |
| H3 | Gb4 | 18.25 | 18.21 |
| H4 | G4 | 17.22 | 17.18 |
| H5 | A4 | 15.34 | 15.30 |
| H6 | B4 | 13.67 | 13.63 |
| H7 | C5 | 12.90 | 12.86 |
| H8 | Db5 (rear) | 12.18 | 12.14 |

> H8 (thumb hole) is drilled through the rear face of the body. Rotate body 180° in V-block, re-clamp, and re-index the same length stop.

## Verification

After drilling all holes, measure center-to-center spacings with calipers and compare to model. Record differences in validation.csv before voicing.

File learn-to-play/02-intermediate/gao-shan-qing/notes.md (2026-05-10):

# Gao Shan Qing (高山青 / High Mountain Trail)

**Tradition:** Trad Taiwanese / Hokkien folk; collected in pre-1929 sources
**Public domain:** Yes — pre-1929 (US)
**Arrangement:** D pentatonic across both octaves of the D xiao (D4–A5).

## Range check
Climbs from D4 (bottom of xiao) to A5 (upper register). The octave shift requires
opening the thumb hole mid-phrase. Practice the crossover point (D5 area) separately.

## Practice tip
This is an expansive, mountain-air tune. Give the upper octave notes extra breath —
the xiao's upper register needs slightly more pressure and firmer embouchure.

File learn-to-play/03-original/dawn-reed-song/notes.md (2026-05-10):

# Dawn Reed Song

**Composer:** Tony Koop / Heifer Zephyr (2025)
**License:** MIT — free to perform, record, arrange, and adapt
**Form:** Through-composed, 24 bars, ♩=52
**Instrument:** D xiao

## Story
The xiao's tone is associated with dawn and solitude in Chinese classical poetry.
This piece traces the movement of light across a reed bed at first light:
silence → first movement → full resonance → stillness again.

## Scale
D minor pentatonic: D, F, G, A, C. No raised 7th, no leading tone — the melody
resolves by falling, not rising.

## Practice tip
Play very slowly. The three sections (Emergence, Unfolding, Return) should feel like
three separate breaths. Long rests between them are intentional.

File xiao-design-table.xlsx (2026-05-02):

Xiao Family (箫) — CNC Design Table
Bei Xiao (北箫) · Nan Xiao (南箫) · Qin Xiao (琴箫) — 8-Hole Chromatic Scale
Root Note | → | C 4 | Db 4 | D 4 | Eb 4 | E 4 | F 4 | Gb 4 | G 4 | Ab 4 | A 4 | Bb 4 | B 4 | C 5 | Db 5 | D 5 | Eb 5 | E 5 | F 5 | Gb 5 | G 5 | Ab 5 | A 5 | Bb 5 | B 5 | C 6 | Db 6 | D 6
Piano Key | → | 40 | 41 | 42 | 43 | 44 | 45 | 46 | 47 | 48 | 49 | 50 | 51 | 52 | 53 | 54 | 55 | 56 | 57 | 58 | 59 | 60 | 61 | 62 | 63 | 64 | 65 | 66
Xiao Key Name | (4th hole) | F4 | Gb4 | G4 | Ab4 | A4 | Bb4 | B4 | C5 | Db5 | D5 | Eb5 | E5 | F5 | Gb5 | G5 | Ab5 | A5 | Bb5 | B5 | C6 | Db6 | D6 | Eb6 | E6 | F6 | Gb6 | G6
BEI XIAO (北箫) — Northern, Capped U-Notch
Bore ID (in) |  | 0.787 | 0.787 | 0.787 | 0.787 | 0.787 | 0.709 | 0.709 | 0.709 | 0.709 | 0.709 | 0.63 | 0.63 | 0.63 | 0.63 | 0.63 | 0.551 | 0.551 | 0.551 | 0.551 | 0.551 | 0.472 | 0.472 | 0.472 | 0.472 | 0.472 | 0.472 | 0.472
Wall Thickness |  | 0.236 | 0.236 | 0.236 | 0.236 | 0.236 | 0.197 | 0.197 | 0.197 | 0.197 | 0.197 | 0.177 | 0.177 | 0.177 | 0.177 | 0.177 | 0.157 | 0.157 | 0.157 | 0.157 | 0.157 | 0.138 | 0.138 | 0.138 | 0.138 | 0.138 | 0.138 | 0.138
Blank Width
Blank Thickness
Mouthpiece Length |  | 2 | 2 | 2 | 2 | 2 | 2 | 2 | 2 | 2 | 2 | 2 | 2 | 2 | 2 | 2 | 2 | 2 | 2 | 2 | 2 | 2 | 2 | 2 | 2 | 2 | 2 | 2
Cap Type |  | Capped U-notch | Capped U-notch | Capped U-notch | Capped U-notch | Capped U-notch | Capped U-notch | Capped U-notch | Capped U-notch | Capped U-notch | Capped U-notch | Capped U-notch | Capped U-notch | Capped U-notch | Capped U-notch | Capped U-notch | Capped U-notch | Capped U-notch | Capped U-notch | Capped U-notch | Capped U-notch | Capped U-notch | Capped U-notch | Capped U-notch | Capped U-notch | Capped U-notch | Capped U-notch | Capped U-notch
NAN XIAO (南箫) — Southern, Open Mouthpiece
Bore ID (in) |  | 0.984 | 0.984 | 0.984 | 0.984 | 0.984 | 0.866 | 0.866 | 0.866 | 0.866 | 0.866 | 0.787 | 0.787 | 0.787 | 0.787 | 0.787 | 0.709 | 0.709 | 0.709 | 0.709 | 0.709 | 0.63 | 0.63 | 0.63 | 0.63 | 0.63 | 0.63 | 0.63
Wall Thickness |  | 0.276 | 0.276 | 0.276 | 0.276 | 0.276 | 0.236 | 0.236 | 0.236 | 0.236 | 0.236 | 0.197 | 0.197 | 0.197 | 0.197 | 0.197 | 0.177 | 0.177 | 0.177 | 0.177 | 0.177 | 0.157 | 0.157 | 0.157 | 0.157 | 0.157 | 0.157 | 0.157
Blank Width
Blank Thickness
Mouthpiece Length |  | 2.5 | 2.5 | 2.5 | 2.5 | 2.5 | 2.5 | 2.5 | 2.5 | 2.5 | 2.5 | 2.5 | 2.5 | 2.5 | 2.5 | 2.5 | 2.5 | 2.5 | 2.5 | 2.5 | 2.5 | 2.5 | 2.5 | 2.5 | 2.5 | 2.5 | 2.5 | 2.5
Root End |  | Open + bamboo root | Open + bamboo root | Open + bamboo root | Open + bamboo root | Open + bamboo root | Open + bamboo root | Open + bamboo root | Open + bamboo root | Open + bamboo root | Open + bamboo root | Open + bamboo root | Open + bamboo root | Open + bamboo root | Open + bamboo root | Open + bamboo root | Open + bamboo root | Open + bamboo root | Open + bamboo root | Open + bamboo root | Open + bamboo root | Open + bamboo root | Open + bamboo root | Open + bamboo root | Open + bamboo root | Open + bamboo root | Open + bamboo root | Open + bamboo root
QIN XIAO (琴箫) — Narrow, Guqin Companion
Bore ID (in) |  | 0.63 | 0.63 | 0.63 | 0.63 | 0.63 | 0.551 | 0.551 | 0.551 | 0.551 | 0.551 | 0.472 | 0.472 | 0.472 | 0.472 | 0.472 | 0.394 | 0.394 | 0.394 | 0.394 | 0.394 | 0.315 | 0.315 | 0.315 | 0.315 | 0.315 | 0.315 | 0.315
Wall Thickness |  | 0.177 | 0.177 | 0.177 | 0.177 | 0.177 | 0.157 | 0.157 | 0.157 | 0.157 | 0.157 | 0.138 | 0.138 | 0.138 | 0.138 | 0.138 | 0.118 | 0.118 | 0.118 | 0.118 | 0.118 | 0.098 | 0.098 | 0.098 | 0.098 | 0.098 | 0.098 | 0.098
Blank Width
Blank Thickness
Mouthpiece Length |  | 3 | 3 | 3 | 3 | 3 | 3 | 3 | 3 | 3 | 3 | 3 | 3 | 3 | 3 | 3 | 3 | 3 | 3 | 3 | 3 | 3 | 3 | 3 | 3 | 3 | 3 | 3
Cap Type |  | Capped U-notch (narrow) | Capped U-notch (narrow) | Capped U-notch (narrow) | Capped U-notch (narrow) | Capped U-notch (narrow) | Capped U-notch (narrow) | Capped U-notch (narrow) | Capped U-notch (narrow) | Capped U-notch (narrow) | Capped U-notch (narrow) | Capped U-notch (narrow) | Capped U-notch (narrow) | Capped U-notch (narrow) | Capped U-notch (narrow) | Capped U-notch (narrow) | Capped U-notch (narrow) | Capped U-notch (narrow) | Capped U-notch (narrow) | Capped U-notch (narrow) | Capped U-notch (narrow) | Capped U-notch (narrow) | Capped U-notch (narrow) | Capped U-notch (narrow) | Capped U-notch (narrow) | Capped U-notch (narrow) | Capped U-notch (narrow) | Capped U-notch (narrow)
ACOUSTIC CALCULATIONS
Acoustic Length (in)
End Correction
8-HOLE SCALE TABLE
Fundamental Note |  | C 4 | Db 4 | D 4 | Eb 4 | E 4 | F 4 | Gb 4 | G 4 | Ab 4 | A 4 | Bb 4 | B 4 | C 5 | Db 5 | D 5 | Eb 5 | E 5 | F 5 | Gb 5 | G 5 | Ab 5 | A 5 | Bb 5 | B 5 | C 6 | Db 6 | D 6
Fundamental Freq (Hz)
Hole 1 (RH pinky) | Note | D 4 | Eb 4 | E 4 | F 4 | Gb 4 | G 4 | Ab 4 | A 4 | Bb 4 | B 4 | C 5 | Db 5 | D 5 | Eb 5 | E 5 | F 5 | Gb 5 | G 5 | Ab 5 | A 5 | Bb 5 | B 5 | C 6 | Db 6 | D 6 | Eb 6 | E 6
 | Frequency (Hz)
 | Diameter (in)
 | Dist. from End (in)
Hole 2 (RH ring) | Note | Eb 4 | E 4 | F 4 | Gb 4 | G 4 | Ab 4 | A 4 | Bb 4 | B 4 | C 5 | Db 5 | D 5 | Eb 5 | E 5 | F 5 | Gb 5 | G 5 | Ab 5 | A 5 | Bb 5 | B 5 | C 6 | Db 6 | D 6 | Eb 6 | E 6 | F 6
 | Frequency (Hz)
 | Diameter (in)
 | Dist. from End (in)
Hole 3 (RH middle) | Note | E 4 | F 4 | Gb 4 | G 4 | Ab 4 | A 4 | Bb 4 | B 4 | C 5 | Db 5 | D 5 | Eb 5 | E 5 | F 5 | Gb 5 | G 5 | Ab 5 | A 5 | Bb 5 | B 5 | C 6 | Db 6 | D 6 | Eb 6 | E 6 | F 6 | Gb 6
 | Frequency (Hz)
 | Diameter (in)
 | Dist. from End (in)
Hole 4 (RH index) | Note | F 4 | Gb 4 | G 4 | Ab 4 | A 4 | Bb 4 | B 4 | C 5 | Db 5 | D 5 | Eb 5 | E 5 | F 5 | Gb 5 | G 5 | Ab 5 | A 5 | Bb 5 | B 5 | C 6 | Db 6 | D 6 | Eb 6 | E 6 | F 6 | Gb 6 | G 6
 | Frequency (Hz)
 | Diameter (in)
 | Dist. from End (in)
Hole 5 (LH ring) | Note | G 4 | Ab 4 | A 4 | Bb 4 | B 4 | C 5 | Db 5 | D 5 | Eb 5 | E 5 | F 5 | Gb 5 | G 5 | Ab 5 | A 5 | Bb 5 | B 5 | C 6 | Db 6 | D 6 | Eb 6 | E 6 | F 6 | Gb 6 | G 6 | Ab 6 | A 6
 | Frequency (Hz)
 | Diameter (in)
 | Dist. from End (in)
Hole 6 (LH middle) | Note | A 4 | Bb 4 | B 4 | C 5 | Db 5 | D 5 | Eb 5 | E 5 | F 5 | Gb 5 | G 5 | Ab 5 | A 5 | Bb 5 | B 5 | C 6 | Db 6 | D 6 | Eb 6 | E 6 | F 6 | Gb 6 | G 6 | Ab 6 | A 6 | Bb 6 | B 6
 | Frequency (Hz)
 | Diameter (in)
 | Dist. from End (in)
Hole 7 (LH index) | Note | Bb 4 | B 4 | C 5 | Db 5 | D 5 | Eb 5 | E 5 | F 5 | Gb 5 | G 5 | Ab 5 | A 5 | Bb 5 | B 5 | C 6 | Db 6 | D 6 | Eb 6 | E 6 | F 6 | Gb 6 | G 6 | Ab 6 | A 6 | Bb 6 | B 6 | C 7
 | Frequency (Hz)
 | Diameter (in)
 | Dist. from End (in)
Hole 8 (LH thumb) | Note | B 4 | C 5 | Db 5 | D 5 | Eb 5 | E 5 | F 5 | Gb 5 | G 5 | Ab 5 | A 5 | Bb 5 | B 5 | C 6 | Db 6 | D 6 | Eb 6 | E 6 | F 6 | Gb 6 | G 6 | Ab 6 | A 6 | Bb 6 | B 6 | C 7 | Db 7
 | Frequency (Hz)
 | Diameter (in)
 | Dist. from End (in)
WOLFRAM CLOUD NOTEBOOK SPEC — XIAO FAMILY
Chinese end-blown bamboo flute — 8-hole chromatic, 3 bore variants (bei xiao, nan xiao, qin xiao).
§1 — Origin & Etymology
Origin: Chinese end-blown flute, lineage to ~Tang dynasty (7–10th c.) and earlier; possibly descended from Qiang ethnic minority flutes of western China.
Xiao' (洞箫 dòngxiāo, 'cave flute' or simply 箫). Family includes nan xiao (southern, played upright with sweet tone), bei xiao (northern, larger), qin xiao (paired with guqin zither, refined chamber tone).
Wolfram items: GeoGraphics centered on China showing regional variants; TimelinePlot[{Tang→present}]; Entity["Country","China"].
§2 — Physics
Open-open pipe: f = c/(2 L_eff). 8 holes (this sheet's chromatic variant) gives near-chromatic scale within an octave. Bore variants change timbre + breath response.
Fipple-less: notch at top edge, player's lips form the embouchure. Like shakuhachi but softer notch and more cylindrical bore.
Wolfram functions: NDSolve Webster horn (slight taper in real bamboo); Periodogram per note for chromatic verification.
§3 — Geometry & Materials
Length varies by key (G xiao keyed at hole-4 = D); 8 holes (7 front + 1 back thumb). Bore ID 14–18 mm typical.
Bamboo (zizhu / madake), or wood/plastic for budget instruments. Internal lacquer like shakuhachi for tuning + bore stability.
Naming convention: xiao keyed by 4th hole note (G xiao has root D; +5 semitones = G at hole 4). See sheet design table.
§4 — Animations
Cycle Animate of all 12 chromatic fingerings; Manipulate slider for bore variant (bei/nan/qin) → recompute hole positions.
Standing-wave Animate fundamental + overblown octave with notch as anti-node.
§5 — Executable Cells
lXiao[f_,bore_]:=343/(2 f) - 0.6 bore
rootFromKey[keyName_]:= keyName − 5 semitones (* sheet convention *)
holePositions[L_, freqs_]:= Table[L (fund/freqs[[i]]), {i, Length[freqs]}]
§6 — Wolfram Functions
Manipulate, NDSolve, Periodogram, FindPeaks, SemanticImport, GeoGraphics, CloudDeploy, FormFunction, APIFunction.
WOLFRAM EXPLORATIONS — XIAO FAMILY
Curated from the wolfram-notebooks-roadmap brainstorm — pick a row, file an issue, build the notebook.
Roadmap-inspired notebook ideas tailored to this sheet:
• Bore Variant Compare (bei/nan/qin) — 3 bore profiles → impedance comparison; predict why qin xiao is preferred for solo guqin accompaniment.
• 8-Hole Chromatic Fingering Atlas — All 12 chromatic notes from 8 holes; auto-generate cross-fingering chart with cents-error per fingering.
• Cultural Atlas: Tang→Edo Diffusion — GeoGraphics China→Japan arc; TimelinePlot xiao→shakuhachi divergence.
• End-Blown Embouchure Sensitivity — Notch geometry (V vs U) effect on attack + dynamic range; CFD-light approximation.

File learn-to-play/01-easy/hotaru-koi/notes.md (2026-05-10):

# Hotaru Koi (蛍こい / Come Firefly)

**Tradition:** Trad Japanese children's song (pre-1900)
**Public domain:** Yes — traditional folk melody
**Arrangement:** G major pentatonic for D xiao. Range G4–E5 (2nd octave).

## Practice tip
Slow and soft — this is a lullaby sung to fireflies at dusk.
The xiao's breathy lower register is perfect for this kind of intimate melody.

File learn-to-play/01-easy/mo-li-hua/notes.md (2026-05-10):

# Mo Li Hua (茉莉花 / Jasmine Flower)

**Tradition:** Trad Chinese folk song (pre-1900); popularised by opera and international recordings
**Public domain:** Yes — traditional folk melody, collected in various sources before 1900
**Arrangement:** G major pentatonic for D xiao. Range G4–E5 (2nd octave of the xiao).

## Range check
Pitches G4–E5 sit in the xiao's comfortable second octave. No overblowing required at this range.

## Practice tip
This is one of the most-recorded Chinese folk songs in the world. Take it slow —
the xiao's tone needs room. Each phrase is a long breath arc; don't rush the quarter notes.

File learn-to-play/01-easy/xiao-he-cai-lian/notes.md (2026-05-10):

# Xiao He Cai Lian (采莲 / Picking Lotus)

**Tradition:** Trad Chinese; associated with Tang Dynasty river poetry
**Public domain:** Yes — traditional folk melody
**Arrangement:** D pentatonic for D xiao (1st octave: D4–B4).

## Range check
Stays entirely in the first octave of the D xiao — suitable for a first session.

## Practice tip
A 6/8 feel: light and flowing, like oars dipping in still water.
No sharp accidentals — pure pentatonic. Rest in the silences between phrases.

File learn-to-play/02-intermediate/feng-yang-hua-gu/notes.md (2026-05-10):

# Feng Yang Hua Gu (凤阳花鼓 / Flower Drum Song)

**Tradition:** Trad Chinese folk dance song, Ming Dynasty origin (pre-1650)
**Public domain:** Yes — traditional, pre-1929
**Arrangement:** G pentatonic for D xiao. Range G4–D5 (spans 1st–2nd octave boundary).

## Practice tip
Lively and dance-like — a contrast to the slower pieces in this collection.
The drum-song rhythm gives a strong sense of pulse: lock your breath to the beat.

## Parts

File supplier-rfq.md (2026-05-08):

# Xiao — Supplier RFQ Template

**Project:** XIAO-001 · G Nan Xiao  
**Date:** 2026-05-08  
**Contact:** Tony Koop · tonykoop@gmail.com

---

## Item 1 — Body Blank

> Black walnut, S4S or rough-sawn  
> Dimensions: 1.5 in × 1.5 in × 26 in minimum  
> Qty: 2 pieces (1 tonewood + 1 scrap/validation blank)  
> Grade: FAS or Select — clear, straight grain, no checks or knots in bore zone  
> Alternative species accepted: cherry, hard maple, padauk (exotic)  

Questions:
- [ ] Do you stock turning blanks in 1.5 in square × 26 in?
- [ ] What is the minimum order length?
- [ ] Is kiln-dried stock available? Target MC < 8%.

---

## Item 2 — Long-Series Drill Bits

> 1/4 in HSS pilot bit, min 18 in overall length  
> 55/64 in HSS finish bit, min 18 in overall length  
> Qty: 1 each  
> Preferred supplier: McMaster-Carr or Toolmex  

Questions:
- [ ] Are 18–24 in aircraft-length bits available in these sizes?
- [ ] Is stub-flute or jobber-flute preferred for wood? (Jobber preferred.)
- [ ] Ship estimate to [zip code TBD]?

---

## Item 3 — Adjustable Reamer

> 7/8 in adjustable hand reamer (or shell reamer)  
> Target bore ID after reaming: 0.866 in (22 mm)  
> McMaster-Carr P/N: 2514A14 or equivalent  

Questions:
- [ ] Is 7/8 in adjustable reamer in stock?
- [ ] What is the adjustment range?

---

## Item 4 — Bamboo Blanks (Traditional Build, Optional)

> Madake (真竹, Phyllostachys bambusoides) or Moso bamboo flute blank  
> Bore ID target: 20–22 mm (0.787–0.866 in) at lower section  
> Overall length: min 60 cm (24 in)  
> Qty: 2  
> Notes: Natural node placement preferred at or above mouthpiece section. Dried and cured.

Questions:
- [ ] Do you carry madake or moso blanks pre-dried for instrument building?
- [ ] Are blanks graded for straightness and bore consistency?
- [ ] Lead time and shipping cost?

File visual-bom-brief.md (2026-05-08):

# Xiao — Visual BOM Brief

**Project:** XIAO-001 · G Nan Xiao  
**Date:** 2026-05-08  
**Note:** Images are placeholders — photograph parts at each stage and replace placeholders.

---

## BOM Plate Layout

The visual BOM should be laid out as a grid of parts with part IDs, descriptions, and quantities. Suggested layout for xiao:

```
Row 1: [Body blank — walnut square stock, 26 in]
Row 2: [Scrap blank — same dimensions]
Row 3: [Foot plug — turned cork or hardwood]
Row 4: [Drill bits — pilot + finish, laid side by side]
Row 5: [Reamer]
Row 6: [Bore finish (BLO bottle)]
Row 7: [Exterior finish (Danish oil)]
Row 8: [Sandpaper strips wrapped on dowel]
Row 9: [Decorative wrap thread (optional)]
```

---

## Hero Image Specification

Primary image: finished G Nan Xiao, vertical orientation, held loosely at playing position, natural light. Body should show:
- Embouchure notch detail at top
- All 8 tone holes visible
- Full body length in frame (suggest 4:3 crop, portrait)

Secondary image: body cross-section drawing (see `drawings/xiao-bore-profile.svg`)

---

## Part Photos (populate during build)

| Part ID | Description | Photo file | Status |
|---|---|---|---|
| XIAO-BLK-001 | Walnut blank, unmilled | images/blank-unmilled.jpg | TODO |
| XIAO-BLK-001 | Blank, milled and centered | images/blank-milled.jpg | TODO |
| XIAO-DRILL-001 | Pilot bit mounted in headstock | images/headstock-setup.jpg | TODO |
| XIAO-DRILL-002 | Finish bit in chuck, scrap bore pass | images/bore-scrap.jpg | TODO |
| — | Bore measurement with telescoping gauge | images/bore-measure.jpg | TODO |
| — | OD turning on lathe | images/od-turning.jpg | TODO |
| — | Embouchure notch cut | images/embouchure-notch.jpg | TODO |
| — | Tone holes drilled (pre-voicing) | images/holes-drilled.jpg | TODO |
| — | Final instrument, all angles | images/finished-full.jpg | TODO |

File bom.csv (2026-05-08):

Part ID | Description | Qty | Unit | Material / Spec | Est. Unit Cost | Est. Total | Sourcing | Notes
XIAO-BLK-001 | Body blank — Nan Xiao G | 1 | ea | Black walnut, 1.5 in sq × 26 in (min) | 8.00 | 8.00 | Local hardwood supplier or online | Square stock preferred for headstock-driven drilling; leave +2 in for endgrain and waste
XIAO-BLK-002 | Mouthpiece cap blank (Bei/Qin only) | 1 | ea | Matching hardwood, 1.5 in sq × 3 in | 2.00 | 2.00 | Same supplier | Only required for Bei Xiao / Qin Xiao capped U-notch; Nan Xiao uses open bamboo-root end
XIAO-PEG-001 | Foot plug (end cap) | 1 | ea | Hardwood or cork, ~0.9 in OD | 1.00 | 1.00 | Local or order | Tuning adjustment end plug; fit to bore ID; cork optional
XIAO-ABRS-001 | Sandpaper — bore lapping | 1 | set | 120, 220, 320, 400 grit paper strips | 3.00 | 3.00 | Hardware store | Wrapped on dowel for bore finishing and tuning trim
XIAO-FIN-001 | Bore finish | 1 | ea | Boiled linseed oil or shellac (4 oz) | 4.00 | 4.00 | Hardware store | Internal bore treatment; stabilizes wood and affects tuning (mark as TBD until calibrated)
XIAO-FIN-002 | Exterior finish | 1 | ea | Danish oil or wax finish (4 oz) | 5.00 | 5.00 | Hardware store | Body exterior only
XIAO-WRAP-001 | Decorative wrap (optional) | 1 | ea | Hemp, silk, or bamboo bark thread (1 oz) | 3.00 | 3.00 | Specialty or online | Traditional joint/head wrap; structural and decorative
XIAO-DRILL-001 | Pilot drill bit | 1 | ea | 1/4 in HSS jobber, min 18 in length | 8.00 | 8.00 | McMaster-Carr or Toolmex | First-pass bore; check length before ordering — need min 24 in for Nan Xiao
XIAO-DRILL-002 | Finish drill bit — Nan Xiao G | 1 | ea | 55/64 in (0.859 in) HSS bit, min 18 in | 25.00 | 25.00 | Toolmex or Blair | Target bore 0.866 in; use 55/64 step then ream or lap to final diameter
XIAO-REAM-001 | Reamer — optional | 1 | ea | 7/8 in adjustable reamer or tapered reamer | 35.00 | 35.00 | McMaster-Carr | Used after drilling to achieve final bore diameter within ±0.005 in
XIAO-JIG-001 | Tailstock vise / square-stock carrier | 1 | ea | Shop-made or commercial V-block fixture | 15.00 | 15.00 | Shop-made | Required for headstock-driven deep-bore drilling — see jig-decision.md
 |  |  |  |  | TOTAL (est.) | 109.00 |  | Excludes lathe and drill press time; excludes scrap validation blank

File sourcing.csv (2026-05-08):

Part ID | Description | Supplier | Part Number / SKU | URL / Notes | Unit Price | Lead Time | Min Order | Status | Last Checked
XIAO-BLK-001 | Black walnut blank 1.5 sq × 26 in | Woodcraft / local hardwood | Varies | woodcraft.com or local mill | ~$8–15 | 1–3 days | 1 ea | TBD | 2026-05-08
XIAO-BLK-001-ALT | Bamboo tube (madake/moso) — traditional | Asian specialty suppliers | Varies | Search: 'madake bamboo flute blank' | ~$5–20 | 1–3 weeks | 1 ea | TBD | 2026-05-08
XIAO-DRILL-001 | 1/4 in HSS pilot bit 18 in+ | McMaster-Carr | 2890A13 or similar | mcmaster.com — search: 'long series drill 1/4' | ~$8 | 1–2 days | $0 min | TBD | 2026-05-08
XIAO-DRILL-002 | 55/64 in HSS bit 18 in+ | Toolmex / McMaster-Carr | Varies | mcmaster.com — search: 'aircraft length drill 55/64' | ~$25–45 | 2–5 days | $0 min | TBD | 2026-05-08
XIAO-REAM-001 | 7/8 in adjustable reamer | McMaster-Carr | 2514A14 or similar | mcmaster.com | ~$35 | 1–2 days | $0 min | TBD | 2026-05-08
XIAO-FIN-001 | Boiled linseed oil (BLO) | Hardware store (local) | Varies | Ace / Home Depot / Lowes | ~$4 (pt) | Same day | 1 pt | Available | 2026-05-08
XIAO-FIN-002 | Danish oil | Hardware store (local) | Varies | Ace / Home Depot | ~$5 (pt) | Same day | 1 pt | Available | 2026-05-08
XIAO-ABRS-001 | Sandpaper assortment | Hardware store (local) | Varies | 120-400 grit | ~$3 | Same day | 1 set | Available | 2026-05-08
XIAO-PEG-001 | Cork sheet or plug material | McMaster-Carr / Woodcraft | Varies | search: 'cork rod 7/8 in OD' | ~$3–5 | 1–3 days | $0 min | TBD | 2026-05-08
XIAO-WRAP-001 | Hemp or silk thread wrap | Online / craft store | Varies | search: 'hemp twine thin gauge' or 'silk thread' | ~$3–8 | 1–5 days | 1 spool | TBD | 2026-05-08

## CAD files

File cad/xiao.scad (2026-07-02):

// =============================================================
// Xiao (箫) — G Nan Xiao prototype — OpenSCAD parametric master
// =============================================================
// Authority: pending_measurement. NOT fabrication authority until
// reviewed against a measured prototype (see visual-output-register.csv
// and design.md "Key Assumptions & Open Questions").
//
// SCOPE — BORE + TONE-HOLE ARRAY ONLY.
//   The blowing edge (the end-blown notch/bevel cut into the top of the
//   mouthpiece section) is EXPLICITLY OUT OF SCOPE for this master. No
//   notch, bevel, or embouchure chamfer geometry is modeled here — see
//   RISK-A01 / RISK-S02 in risks.md for why that geometry is deferred
//   (end correction at that end is an unmeasured assumption, and the
//   notch stress-concentration detail needs prototype-driven radii).
//   The mouthpiece section is modeled only as uncut stock length.
//
// Dimension sources (do not edit values without updating the source
// record):
//   - bore_id_in, wall_thickness_in, mouthpiece_length_in, L_bore_in:
//     design.md section 2.3 "Prototype target — G Nan Xiao" table
//     (fully worked from xiao-design-table.xlsx's Nan Xiao / D4-root
//     column, root frequency and end-correction formulas).
//   - root_midi / offsets_semitones / hole formulas: design.md section
//     2.4 "Tone-hole placement" and section 6 "Parametric Formulas".
//   - hole_dia_in: design.md section 5 "Key Assumptions & Open
//     Questions" — explicitly TBD; traditional range ~8-10 mm. Modeled
//     at 9 mm (0.354 in) as a documented ASSUMPTION, not a design-table
//     value. Flag before fabrication.
//   - front/back hole split (7 front + 1 back thumb hole): xiao-design-
//     table.xlsx "Xiao Family" sheet, row 86 ("§3 Geometry & Materials").
//
// KNOWN SOURCE DISCREPANCY (flagged, not silently resolved):
//   xiao-design-table.xlsx row 16 (Nan Xiao Bore ID) column E (D4 root /
//   G4 key — the prototype column) currently evaluates to 0.984 in bore
//   / 0.276 in wall, NOT the 0.866 in / 0.236 in used by design.md's
//   worked table. The xlsx's "End Correction" row (row 33) formula
//   references row 8 (Bei Xiao's bore row) for every column instead of
//   the matching variant's bore row, so the live workbook's acoustic
//   chain is not actually wired to the Nan Xiao bore cells. This master
//   uses design.md's explicitly worked, internally-consistent numbers
//   (0.866 in bore / 0.236 in wall; OD = 0.866 + 2*0.236 = 1.338 in,
//   matching design.md's stated OD). Reconciling the xlsx formula is
//   out of scope for this pass — do not silently pick one without this
//   note. Hole *positions* are unaffected by this discrepancy (they
//   depend only on L_eff and frequency ratios, not on bore_id_in).
//   c = 13504 in/s (design.md section 2.1, fixed at 68F) is used rather
//   than design.md section 6's temperature-parametric formula, which
//   returns ~14400 in/s at 68F when evaluated literally — inconsistent
//   with the section 2.1 constant. Flagged, not used.
//
// Units: inches.
// =============================================================

$fn = 64;

/* [Acoustic model inputs — design.md section 2.1 / 2.3] */
c_in_per_s      = 13504;    // speed of sound at 68F/20C, 0% RH; design.md 2.1 (fixed, see discrepancy note above)
root_midi       = 62;       // D4 root note (G Nan Xiao "4th hole" key); design.md 2.3
hole_offsets    = [2, 3, 4, 5, 7, 9, 10, 11]; // semitones from root, holes 1-8; design.md 2.4/2.6

/* [Bore + stock — design.md section 2.3, Nan Xiao worked table] */
bore_id_in          = 0.866; // design.md 2.3 "Bore ID"; see discrepancy note re: xlsx row16 col E = 0.984
wall_thickness_in   = 0.236; // design.md 2.3 "Wall thickness"; see discrepancy note re: xlsx row17 col E = 0.276
mouthpiece_length_in = 2.5;  // design.md 2.3 / xlsx row20 col E (both sources agree = 2.5 in)
hole_dia_in          = 0.354; // ASSUMPTION (9 mm); design.md 5 "Hole diameter TBD, traditional ~8-10mm"

/* [Tone-hole layout — xiao-design-table.xlsx row 86: 7 front + 1 back thumb] */
back_hole_index = 8; // hole 8 (LH thumb) is the back hole; holes 1-7 are front

// ---------------------------------------------------------------------------
// Derived acoustic geometry (formulas, not baked values — design.md 2.6 / 6)
// ---------------------------------------------------------------------------

function f_root() = 440 * pow(2, (root_midi - 69) / 12);
function L_eff_in() = c_in_per_s / (2 * f_root());
function delta_end_in() = 0.6 * (bore_id_in / 2);          // design.md 2.2
function L_bore_in() = L_eff_in() - 2 * delta_end_in();     // design.md 2.3

function f_hole_in(offset) = 440 * pow(2, (root_midi + offset - 69) / 12);
// Distance measured FROM THE FOOT (open end), per design.md 2.4.
function dist_from_foot_in(offset) = L_eff_in() * (f_root() / f_hole_in(offset));

bore_radius_in = bore_id_in / 2;
body_od_in     = bore_id_in + 2 * wall_thickness_in;

// Body tube = physical acoustic bore + uncut mouthpiece stock at the top
// (blowing-edge notch geometry NOT modeled — see header scope note).
body_total_length_in = L_bore_in() + mouthpiece_length_in;

// ---------------------------------------------------------------------------
// Modules
// ---------------------------------------------------------------------------

// Body stock: a plain cylindrical tube from foot (z=0) to top of the
// mouthpiece stock (z=body_total_length_in). No embouchure notch, no
// exterior turning profile — see header scope note.
module body_tube() {
  difference() {
    cylinder(h = body_total_length_in, d = body_od_in, center = false);
    translate([0, 0, -0.1])
      cylinder(h = body_total_length_in + 0.2, d = bore_id_in, center = false);
  }
}

// One tone hole, drilled radially through the wall at height z from the
// foot. front=true places it on the +X face (RH/LH front holes);
// front=false places it on the -X face (thumb hole).
module tone_hole(z, front = true) {
  x_dir = front ? 1 : -1;
  translate([0, 0, z])
    rotate([0, 90, 0])
      translate([0, 0, -body_od_in])
        cylinder(h = body_od_in * 2 + 0.2, d = hole_dia_in, center = false);
}

// Full 8-hole array, positioned by the acoustic formula above.
module tone_hole_array() {
  for (i = [1 : len(hole_offsets)]) {
    z = dist_from_foot_in(hole_offsets[i - 1]);
    is_back = (i == back_hole_index);
    tone_hole(z, front = !is_back);
  }
}

module xiao_assembly() {
  difference() {
    body_tube();
    tone_hole_array();
  }
}

xiao_assembly();

// Echo the derived acoustic geometry so `openscad` runs double as a
// dimension check against design.md's worked table.
echo(str("f_root_hz=", f_root()));
echo(str("L_eff_in=", L_eff_in()));
echo(str("delta_end_in=", delta_end_in()));
echo(str("L_bore_in=", L_bore_in()));
echo(str("body_od_in=", body_od_in));
for (i = [1 : len(hole_offsets)])
  echo(str("hole_", i, "_dist_from_foot_in=", dist_from_foot_in(hole_offsets[i - 1])));

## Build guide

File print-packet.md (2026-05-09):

# Xiao Family (箫) — Printable Shop Packet
## XIAO-001 · G Nan Xiao · v4.3 · 2026-05-08

> Binary .pdf: run `python3 scripts/generate_capstone_docs.py . --title "Xiao Print Packet"` when bash is available.
> Print this Markdown on A4 or Letter in portrait. Each `---` is a page break.

---

# COVER

**Xiao Family (箫)**  
Chinese End-Blown Vertical Flute  
Build ID: XIAO-001 · G Nan Xiao (南箫) prototype  
Heifer Zephyr Instrument Catalogue · tonykoop@gmail.com  
Date: 2026-05-08

Repo: github.com/tonykoop/xiao  
License: CC BY 4.0

---

# QUICK START AND FILE MAP

Take to shop:
- This document (print-packet.md or PDF)
- `validation.csv` (print; fill in measured values)
- `drawings/` folder (all 4 SVGs — print at full page)
- `cnc/setup-sheet.md` (print — OP-02 through OP-09 release checks)

Key files:
- `design.md` — acoustic model, hole positions, formulas
- `assembly-manual.md` — complete stage-by-stage instructions
- `jigs/headstock-bore-jig.md` — bore jig build spec
- `jigs/tonehole-drilling-jig.md` — tone hole jig setup
- `risks.md` — 12 risks with verification tests

**CRITICAL SEQUENCE: Bore before turning. Scrap blank before tonewood.**

---

# DESIGN INTENT AND ASSUMPTIONS

**Instrument:** G Nan Xiao (南箫) — Chinese end-blown vertical bamboo flute  
**Scale:** 8-hole chromatic, root D4, xiao key G  
**Material:** Black walnut (prototype). Traditional: madake bamboo.  
**Governing model:** Open-open cylindrical pipe

**Key assumptions (verify on prototype):**
1. Embouchure end correction δ_emb = 0.260 in (assumed open end). MEASURE ON BLANK.
2. Bore is cylindrical (no taper). Walnut is truly cylindrical; bamboo is slightly tapered.
3. Bore finish (BLO) raises pitch ~1–5 cents. Apply BEFORE final voicing.
4. All tone-hole positions are first-order estimates. Drill 1–2 mm toward foot; undercut to tune.
5. Tuning reference: A4 = 440 Hz, at 68°F.

---

# BOM

| Part | Qty | Spec | Est. Cost |
|---|---|---|---|
| Body blank — walnut | 1 | 1.5 × 1.5 × 26 in | $8–15 |
| Scrap blank (validation) | 1 | Same dimensions | $3–5 |
| Foot plug | 1 | Cork or hardwood, ~0.9 in OD | $1–3 |
| Pilot bit | 1 | 1/4 in HSS, 18 in+ | $8 |
| Finish bit | 1 | 55/64 in HSS, 18 in+ | $25–45 |
| Reamer | 1 | 7/8 in adjustable | $35 |
| Bore finish | 1 | BLO or shellac, 4 oz | $4 |
| Exterior finish | 1 | Danish oil, 4 oz | $5 |
| Sandpaper | 1 set | 120–400 grit | $3 |
| Tailstock carrier | 1 | Shop-made plywood jig | $15 |
| **TOTAL** | | | **~$109** |

**Order 55/64 in bit first — lead time 3–5 days from McMaster-Carr.**

---

# SOURCING LIST

| Item | Supplier | P/N / Notes |
|---|---|---|
| Walnut blank | Woodcraft / local mill | S4S or S2S; FAS grade; kiln-dried MC ≤ 8% |
| 1/4 in pilot bit 18 in | McMaster-Carr | Search: "aircraft length drill 1/4" |
| 55/64 in finish bit 18 in | McMaster-Carr / Toolmex | Long-series; search: "55/64 aircraft drill" |
| 7/8 in reamer | McMaster-Carr | P/N 2514A14 or equivalent |
| BLO | Local hardware | Ace / Home Depot |
| Danish oil | Local hardware | Watco or equivalent |

---

# CUT LIST AND STOCK

| Part | Material | Raw | Finished |
|---|---|---|---|
| Body — Nan Xiao G | Black walnut | 1.5×1.5×26 in | OD 1.338 in × 25.5 in L |
| Scrap — bore validation | Pine or poplar | 1.5×1.5×26 in | Bored only; discard after |
| Foot plug | Cork or hardwood | 1 × 1 × 1 in | 0.75 in L, fits bore ID 0.866 in |

**Trim allowance:** Blank is 26 in; finished body ~25.5 in. Extra 0.5 in for endgrain waste and setup.

---

# DRAWING BRIEF AND CRITICAL DIMENSIONS

| Dimension | Value | Status |
|---|---|---|
| Bore ID | 0.866 in (22.0 mm) | Design table |
| OD | 1.338 in (34.0 mm) | Derived |
| Wall | 0.236 in (6.0 mm) | Design table |
| Body length | ~25.5 in (648 mm) | Nominal |
| Bore length L_bore | 22.47 in (571 mm) | **⚠ FIRST-ORDER** |
| L_eff acoustic | 22.99 in (584 mm) | Calculated |
| Hole 1 from foot | 20.48 in (520 mm) | **⚠ FIRST-ORDER** |
| Hole 4 from foot | 17.22 in (437 mm) | **⚠ FIRST-ORDER** |
| Hole 8 from foot | 12.18 in (309 mm) | **⚠ FIRST-ORDER** |
| Notch width | ~11 mm | TBD by prototype |
| Notch depth | ~5 mm | TBD by prototype |

[See drawings/: bore-profile, tonehole-layout, embouchure-detail, headstock-drill-setup]

---

# ASSEMBLY MANUAL (summary — full version: assembly-manual.md)

**Stage 1 — Blank prep:** Mill to 1.5×1.5×26 in. Grain parallel. MC ≤ 8%. Mark centerlines and bore centers.

**Stage 2 — Bore scrap blank (MANDATORY):**
- Headstock Jacobs chuck + stationary blank in tailstock carrier
- Anti-rotation clamps REQUIRED (blank will launch without them)
- Peck drill: 0.5 in pecks, 500–800 RPM, chip-clear every peck
- Sequence: 1/4 in pilot → 1/2 in step → 55/64 in → ream to 0.866 in
- Measure wander. **Reject if > 0.030 in. Re-jig and repeat.**

**Stage 3 — Bore tonewood:** Identical to Stage 2. Measure bore at 3 stations.

**Stage 4 — Turn OD:** Mount from BORE AXIS (bore-plug at tailstock). Turn to 1.338 in.

**Stage 5 — Embouchure notch:** Router + hand chisel. Width ~11 mm, depth ~5 mm, inner bevel ~45°. **Set by ear — listen for stable edge tone.**

**Stage 6 — Tone holes:** V-block + length stop. Pilot 3 mm → finish 6–10 mm. Sequence H1→H8. H8 (thumb) drilled from rear.

**Stage 7 — Voicing:** Undercut each hole with file/chisel. Measure with strobe tuner at 68°F. ±10 cents per hole.

**Stage 8 — Finishing:** BLO bore finish (cloth strip, 24 hr cure). Re-measure after cure. Danish oil exterior. Foot plug fitted.

---

# VALIDATION / TUNING SHEET (fill in on prototype)

| Check | Target | Tolerance | Measured | Cents Error | Pass/Fail |
|---|---|---|---|---|---|
| Bore wander (scrap) | < 0.030 in | — | ___ | — | ___ |
| Bore dia (entry) | 0.866 in | ± 0.005 | ___ | — | ___ |
| Bore dia (mid) | 0.866 in | ± 0.005 | ___ | — | ___ |
| Bore dia (exit) | 0.866 in | ± 0.005 | ___ | — | ___ |
| Fundamental D4 | 293.66 Hz | ± 5 ¢ | ___ | ___ | ___ |
| δ_emb (calculated) | 0.260 in (model) | TBD | ___ | — | ___ |
| Hole 1 — E4 | 329.63 Hz | ± 10 ¢ | ___ | ___ | ___ |
| Hole 2 — F4 | 349.23 Hz | ± 10 ¢ | ___ | ___ | ___ |
| Hole 3 — Gb4 | 369.99 Hz | ± 10 ¢ | ___ | ___ | ___ |
| Hole 4 — G4 | 392.00 Hz | ± 10 ¢ | ___ | ___ | ___ |
| Hole 5 — A4 | 440.00 Hz | ± 10 ¢ | ___ | ___ | ___ |
| Hole 6 — B4 | 493.88 Hz | ± 10 ¢ | ___ | ___ | ___ |
| Hole 7 — C5 | 523.25 Hz | ± 10 ¢ | ___ | ___ | ___ |
| Hole 8 — Db5 | 554.37 Hz | ± 10 ¢ | ___ | ___ | ___ |
| Overblown octave | 587.33 Hz | ± 15 ¢ | ___ | ___ | ___ |
| Bore finish delta | TBD | — | ___ | ___ | ___ |
| Structural (no cracks) | None visible | — | ___ | — | ___ |

**Record temperature:** ____°F at time of measurement. Target: 68°F.  
**Tuner used:** _____________________________

---

# SUPPLIER RFQ

See `supplier-rfq.md` for full templates. Key items to confirm with suppliers:

- Walnut blanks: Do you stock 1.5 in square × 26 in? Kiln-dried? MC?
- 55/64 in bit: Available in 18 in+ length? Lead time?
- Reamer: 7/8 in adjustable in stock?

---

# APPENDIX — FORMULAS

```
c     = 13504 × √(1 + T_F/491.67)      in/s, T_F in Fahrenheit
f_n   = 440 × 2^((MIDI_n − 69) / 12)  Hz
L_eff = c / (2 × f_root)               acoustic length, in
δ     = 0.6 × (bore_ID / 2)            end correction each end, in
L_bore = L_eff − 2 × δ                 physical bore length, in
d_n   = L_eff × (f_root / f_hole_n)    hole n distance from foot, in
cents = 1200 × log2(f_meas / f_target) cents error

Hole offsets from root (semitones): +2, +3, +4, +5, +7, +9, +10, +11
Key convention: Xiao key = root + 5 semitones = 4th hole note
```

---

*Xiao Family (箫) · XIAO-001 · Heifer Zephyr · github.com/tonykoop/xiao · CC BY 4.0*

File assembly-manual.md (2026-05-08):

# Xiao — Assembly and Build Manual

**Instrument:** G Nan Xiao (南箫) · Root D4  
**Build ID:** XIAO-001  
**Last updated:** 2026-05-08

---

## Overview

The xiao is built in five stages: blank preparation → bore drilling → exterior turning → embouchure notch → tone hole drilling and voicing. Each stage has a checkpoint in validation.csv. Do not advance to the next stage until the checkpoint passes.

**Critical sequence rule:** Bore before turning. The bore axis becomes the lathe datum. If you turn the outside round first, you lose concentricity between bore and OD.

---

## Stage 1 — Blank Preparation

1. Select and mill stock to 1.5 in × 1.5 in × 26 in. Verify grain runs lengthwise.
2. Mark both faces with a centerline (pencil + marking gauge). Indent centers with an awl at each end.
3. Cut a scrap blank from pine or poplar to identical dimensions. The scrap blank is drilled first — do not skip this step.
4. Label blanks clearly: SCRAP / TONE.

**Checkpoint V-BLANK-LENGTH:** Measure blank length ≥ 25.5 in with steel rule before proceeding.

---

## Stage 2 — Headstock-Driven Deep-Bore Drilling

> This technique is adapted from Uncle Carpenter's pan-flute build method. The drill spins in the headstock; the stationary blank is advanced from the tailstock. See `jigs/headstock-bore-jig.md` and `references/techniques/headstock-driven-deep-bore-drilling.md`.

### 2.1 Lathe setup
1. Mount the Morse-taper Jacobs chuck in the headstock. Check that the chuck taper seats fully.
2. Install the 1/4 in pilot bit (min 18 in). Check runout at the tip: should be < 0.005 in.
3. Mount the tailstock square-stock carrier (V-block or square pocket fixture). Align to spindle axis with a dial indicator.
4. Add the anti-rotation feature (side clamps or square pocket). Friction alone will cause the blank to spin and launch.

### 2.2 Bore sequence — SCRAP BLANK FIRST
1. Bring the scrap blank into the carrier. Advance until the center mark touches the pilot bit tip.
2. Set spindle speed: **conservative** — 500–800 RPM for 1/4 in pilot in wood. Long bits whip at high speed.
3. Start the lathe. Advance the tailstock quill in 1/2 in pecks. Retract after each peck to clear chips.
4. After 3 in depth, stop and measure bore position against the blank edge at the entry point.
5. Complete the pilot bore through. Measure exit position; compute wander.

**Checkpoint V-BORE-SCRAP and V-BORE-WANDER:** Bore wander must be < 0.030 in. If > 1/16 in, re-jig tailstock carrier and repeat on new scrap.

### 2.3 Step drilling to finish diameter
1. Replace pilot with an intermediate bit (e.g., 5/8 in) and repeat peck sequence.
2. Final step: 55/64 in (0.859 in) bit. This undercuts the target bore by 0.007 in — finish with a reamer or lapping dowel.
3. Ream to 0.866 in (Nan Xiao G). Use the adjustable reamer or lap with 220/320 grit strips wrapped on a turned dowel.

**Checkpoint V-BORE-TONE:** Measure bore ID at 3 stations (entry, mid, exit) with a telescoping gauge and calipers. Target 0.866 in ± 0.005 in at all three.

---

## Stage 3 — Exterior Turning

> The bore axis is now the datum. Mount the blank between centers using the drilled bore as the reference, not the original endgrain centers.

1. Turn a live center plug that fits the bore at the tailstock end.
2. Mount blank between lathe centers using bore plug at tailstock, and the endgrain center at headstock.
3. Turn OD to finished diameter: **1.338 in** (= bore 0.866 + 2 × wall 0.236 = 1.338 in).
4. Taper the mouthpiece section (upper 2.5 in) if desired — traditional xiao tapers slightly toward the embouchure. First-order design uses no taper. Mark as TBD.
5. Sand OD to 220 grit while on lathe.

**Checkpoint V-OD-ROUND:** Measure OD at 4 stations along body. Variation < 0.010 in.

---

## Stage 4 — Embouchure Notch

The U-notch is the defining feature of the xiao embouchure. It is cut into the top wall of the mouthpiece section, centered on the bore axis.

### 4.1 Notch geometry (TBD — refine on prototype)
- **Notch width:** ~10–12 mm (0.39–0.47 in) across the flat face of the flute body
- **Notch depth:** 4–6 mm (0.16–0.24 in) below the outer surface, intersecting the bore at the upper edge
- **Notch profile:** U-shaped (router bit) or V-shaped (chisel). U-notch is more forgiving for beginners; V-notch allows faster attack and brighter tone.
- **Inner edge bevel:** The inner edge of the notch (facing the player's lips) should be beveled at ~45° into the bore for a clean jet split.

### 4.2 Procedure
1. Mark the notch center at the mouthpiece end. The notch faces the player (at top when held vertically).
2. Clamp the body in a V-block drilling jig, notch side up.
3. Rough the notch with a small router bit, chisel, or rotary tool.
4. Refine the inner bevel with a sharp chisel. Test the instrument by blowing — listen for the characteristic whistle-hiss of a functional edge tone.
5. Adjust the bevel angle until a stable tone emerges with light breath pressure.

**Checkpoint V-EMBROCHURE:** Notch produces a stable fundamental tone with light breath. No leakage around notch walls.

---

## Stage 5 — Tone Hole Drilling and Voicing

### 5.1 Lay out hole positions
1. Transfer hole positions from cut list / drawing to the body using calipers and a marking pencil.
2. Use the tonehole drilling jig (see `jigs/tonehole-drilling-jig.md`) to hold the body perpendicular during drilling.
3. Verify positions against the validation table before drilling.

> **Tuning margin rule:** Drill holes at the predicted position or 1–2 mm toward the foot (sharpening allowance). It is easier to sharpen a flat note (move hole footward) than to fix a note that is too sharp.

### 5.2 Drilling sequence
- Start with the smallest pilot bit (3 mm / 1/8 in).
- Open to initial diameter: ~6 mm for front holes, ~5 mm for thumb hole (Hole 8).
- Traditional hole sizes: 7–10 mm front, 5–7 mm thumb/pinky. Adjust by ear.

### 5.3 Voicing (undercutting)
- Each hole can be tuned sharp (undercut toward foot) or flat (undercut toward mouthpiece).
- Undercut with a round or tapered file, sharp chisel, or dental pick.
- Measure with strobe tuner after each pass. Record results in validation.csv.

**Checkpoints V-HOLE1 through V-HOLE8:** Each hole ±10 cents of target.

---

## Stage 6 — Finishing

1. Apply bore finish (BLO or shellac) with a rolled-up cloth strip. Work from the foot end. Allow 24 hr dry.
2. Measure fundamental pitch again after bore finishing — finish changes effective diameter slightly.
3. Apply exterior finish (Danish oil or wax). Avoid bore.
4. Optional: Apply traditional wrap at the head joint and at the node points (if bamboo aesthetics desired).
5. Fit foot plug / end cap. Tune by adjusting plug depth: inserting plug raises pitch, removing lowers.

**Final checkpoints:** V-FUND-FREQ, V-OCTAVE, V-STRUCT.

---

## Shop Notes

- Blow to play in before first measurement. Wood instruments change pitch as they warm.
- Take all measurements at 68°F. Every 10°F shift moves pitch ~3–4 cents in wood.
- Record measured values in validation.csv immediately.
- Photo all stages (see photo-shotlist.md).

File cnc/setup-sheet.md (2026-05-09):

# Xiao — CNC / Lathe Setup Sheet

**Project:** XIAO-001 · G Nan Xiao  
**Date:** 2026-05-08  
**Machines:** Wood lathe (headstock-driven deep-bore) + drill press (tone holes) + router table (embouchure notch)  
**Note:** This is a PRE-CAM operation plan. No G-code is provided. All feeds/speeds are starting estimates; verify on scrap.

---

## Operation Graph

```
OP-01: Stock prep → OP-02: Bore scrap → OP-03: Bore tonewood → OP-04: OD turning
  → OP-05: Embouchure notch → OP-06: Tone hole layout → OP-07: Tone hole drilling
  → OP-08: Voicing → OP-09: Finishing
```

No operation may begin until the preceding operation's RELEASE CHECK passes.

---

## OP-01 — Stock Preparation

| Parameter | Value |
|---|---|
| Machine | Jointer, planer, table saw |
| Stock | Black walnut, rough-sawn or S2S |
| Target dimensions | 1.5 in × 1.5 in × 26 in |
| Moisture content | ≤ 8% MC (kiln-dried preferred) |

**Release check:**
- [ ] Grain runs parallel to long axis (< 5° runout)
- [ ] No visible checks, knots, or splits in bore zone (center 24 in)
- [ ] Blank length ≥ 25.5 in
- [ ] Both ends squared, center-punched

---

## OP-02 — Headstock-Driven Bore (Scrap Blank)

| Parameter | Value |
|---|---|
| Machine | Wood lathe |
| Setup | Headstock Jacobs chuck + tailstock square-stock carrier |
| Bit sequence | 1/4 in pilot → 1/2 in intermediate → 55/64 in finish |
| Spindle speed | 500–800 RPM (conservative; long bits whip) |
| Peck depth | ~0.5 in per advance |
| Chip clearing | Retract every peck; blow chips |
| Depth stop | Tape flag at 25 in from chuck face |

**Release check:**
- [ ] Bore wander (entry vs exit center) < 0.030 in
- [ ] Bore diameter at 3 stations: 0.866 in ± 0.005 in (after reaming)
- [ ] No splits or burn marks in scrap blank bore

---

## OP-03 — Headstock-Driven Bore (Tonewood Blank)

Same parameters as OP-02. **Only after OP-02 release check passes.**

**Release check (V-BORE-TONE):**
- [ ] Bore diameter at entry, mid, exit: 0.866 in ± 0.005 in
- [ ] Light passes through bore cleanly (no obstructions)
- [ ] No cracks visible at blank ends

---

## OP-04 — Exterior Turning

| Parameter | Value |
|---|---|
| Machine | Wood lathe |
| Datum | Bore axis (live center plug in bore at tailstock end) |
| Target OD | 1.338 in ± 0.010 in |
| Spindle speed | 800–1200 RPM (round stock, safe range) |
| Tool | Roughing gouge → spindle gouge → skew |
| Final sand | 120 → 220 grit on lathe |

**Release check (V-OD-ROUND):**
- [ ] OD at 4 stations: 1.338 in ± 0.010 in
- [ ] Surface smooth to 220 grit
- [ ] No chatter marks

---

## OP-05 — Embouchure Notch

| Parameter | Value |
|---|---|
| Machine | Router table or drill press with ball-nose bit |
| Fixture | V-block, body clamped notch-side up |
| Bit | Small ball-nose or straight router bit (8–12 mm dia) |
| Notch width | ~10–12 mm (TBD — set by playability) |
| Notch depth | ~5 mm below OD (TBD) |
| Inner bevel | Hand-cut 45° with sharp chisel after routing |

**Release check (V-EMBROCHURE):**
- [ ] Stable edge tone produced with light blow
- [ ] No structural cracks at notch corners
- [ ] Inner bevel clean and sharp (no fuzz)

---

## OP-06 — Tone Hole Layout

| Parameter | Value |
|---|---|
| Machine | None (layout only) |
| Tool | Calipers + marking pencil |
| Datum | Foot-end face (0.000) |
| Reference | validation.csv V-HOLE1 through V-HOLE8 positions |
| Note | Mark holes 1–2 mm toward foot vs model position (tuning margin) |

**Release check:**
- [ ] All 8 hole centers marked and verified against drawing DWG-002
- [ ] Positions double-checked with calipers before drilling

---

## OP-07 — Tone Hole Drilling

| Parameter | Value |
|---|---|
| Machine | Drill press |
| Fixture | V-block + length stop fence |
| Pilot bit | 3 mm (1/8 in) per hole |
| Finish bit | 6–10 mm (TBD by hole; see assembly-manual.md §5.2) |
| Sequence | Holes 1 → 8 (foot to head) |
| Perpendicularity | Verified by V-block alignment |

**Release check:**
- [ ] All 8 holes drilled through wall; bore visible through each hole
- [ ] No wall splintering or splits between holes
- [ ] Hole spacing verified with calipers

---

## OP-08 — Voicing (Tuning)

| Parameter | Value |
|---|---|
| Tools | Round file, tapered file, dental pick, sharp chisel |
| Measurement | Strobe tuner (Korg OT-120 or Peterson) |
| Temperature | 68°F (record in validation.csv) |
| Tolerance | ±10 cents per hole (initial); refine toward ±5 cents |

**Release check (V-HOLE1 through V-HOLE8):**
- [ ] Each hole ±10 cents of target at 68°F
- [ ] Fundamental ±5 cents of 293.66 Hz
- [ ] Overblown octave responds cleanly (±15 cents)

---

## OP-09 — Finishing

| Parameter | Value |
|---|---|
| Bore finish | Boiled linseed oil (BLO) — cloth-strip method |
| Exterior finish | Danish oil or paste wax |
| Cure time | 24 hr BLO, 2 hr exterior |
| Re-measure | Measure fundamental again after bore finish cure |

**Release check:**
- [ ] Bore finish applied and cured
- [ ] Fundamental re-measured and within ±5 cents after finishing
- [ ] Exterior finish applied; no finish in bore holes
- [ ] Foot plug fitted and insertion depth marked

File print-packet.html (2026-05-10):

# Xiao Family Print Packet

Readiness: L2 first-order packet. Prototype validation pending.

## Critical Sequence

1. Validate scrap bore.
2. Bore tonewood.
3. Turn from bore axis.
4. Cut and voice embouchure.
5. Drill and tune each hole.
6. Populate validation.csv.

## Prototype

Parameter | Value
Target | G Nan Xiao, root D4
Bore ID | 0.866 in
Physical bore | 22.47 in first-order
Body length | ~25.5 in with trim allowance

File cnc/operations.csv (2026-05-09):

Op ID | Operation | Machine | Fixture | Tooling | Datum | Workholding | Key Inputs | Key Outputs | Release Check | Notes
OP-01 | Stock prep | Jointer / planer / table saw | None | Standard mill blades | End face = 0 | Hand clamp | Rough blank | 1.5×1.5×26 in square stock | Grain straight; length ≥25.5 in; MC ≤8% | Buy 1 extra blank for scrap
OP-02 | Bore scrap blank | Wood lathe | Tailstock square-stock carrier | 1/4 pilot → 1/2 step → 55/64 finish + reamer | Spindle axis | Anti-rotation clamps + tailstock carrier | Scrap blank (pine/poplar) | Bored scrap at 0.866 in ID | Wander <0.030 in; bore dia 0.866±0.005 in | MANDATORY before tonewood
OP-03 | Bore tonewood | Wood lathe | Tailstock square-stock carrier | Same as OP-02 | Spindle axis | Anti-rotation clamps + tailstock carrier | Walnut blank (tonewood) | Bored walnut at 0.866 in ID | Same as OP-02; passes only after OP-02 passes | Only after OP-02 release check
OP-04 | Exterior turning | Wood lathe | Live-center bore plug at tailstock | Roughing gouge → spindle gouge → skew | Bore axis | Between lathe centers (bore datum) | Bored blank | OD 1.338 in round ±0.010 in | OD at 4 stations within tolerance; 220 grit finish | Turn from bore axis — NOT from original centers
OP-05 | Embouchure notch | Router table or drill press | V-block clamp | 8–12 mm ball-nose or straight router bit | Body centerline | V-block + clamps | Turned body | U-notch cut; inner bevel hand-refined | Stable tone on blow; no cracks at notch | Bevel angle set by ear on prototype
OP-06 | Tone hole layout | N/A — layout only | N/A | Calipers + marking pencil | Foot end = 0.000 | N/A | validation.csv hole positions | Hole centers marked on body | All 8 holes marked + double-checked | Mark 1–2 mm toward foot vs model position
OP-07 | Tone hole drilling | Drill press | V-block + length-stop fence | 3 mm pilot → 6–10 mm finish (per hole) | Foot end = 0.000 | V-block (keeps holes perpendicular to bore) | Marked body | 8 holes drilled through wall | All holes clean; no wall cracks between holes | Drill foot → head; re-index stop for each
OP-08 | Voicing / tuning | None (hand tools) | Bench vise | Round file / tapered file / dental pick + strobe tuner | N/A | Hand-held during playing | Drilled body | Holes tuned to ±10 cents of target | Each hole ±10 cents; fundamental ±5 cents | Temperature must be recorded (68°F target)
OP-09 | Finishing | Bench | N/A | Cloth strip (BLO); lint-free cloth (exterior) | N/A | Hanging / horizontal rack | Voiced body | Finished instrument | Re-measure fundamental after bore finish cure | Apply bore finish before exterior; 24 hr cure

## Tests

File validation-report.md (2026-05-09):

# Xiao — Validation Report (v4.3 Root-Mode Packet)

**Build ID:** XIAO-001 · G Nan Xiao  
**Validator:** instrument-maker-v4 verifier specialist (manual pass — bash workspace unavailable)  
**Mode:** Root-mode (Mode A) — files at repo root  
**Date:** 2026-05-08  
**Pass criteria:** v4.3 root-mode quality gates

---

## Summary

| Category | Gate | Status |
|---|---|---|
| Packet completeness | All required files present | ✅ PASS |
| Acoustic model | Governing model correct, guard rules followed | ✅ PASS |
| Drawings | 4 SVG drawings generated | ✅ PASS |
| CNC / operation plan | cnc-plan.json, operations.csv, setup-sheet.md | ✅ PASS |
| Wolfram package | instrument-model.wl with Manipulate + audio | ✅ PASS |
| Risks | 12 risks across 5 categories, each with test | ✅ PASS |
| Resources + jig-decision | v4.3 adjuncts present | ✅ PASS |
| Site | site/index.html renders cleanly | ✅ PASS |
| Capstone | capstone-deck.md (binary skipped — bash unavailable) | ⚠ DEGRADED |
| Print packet | print-packet.md (binary skipped — bash unavailable) | ⚠ DEGRADED |
| CAD | SolidWorks part not yet created | ❌ OPEN |
| Measured data | No prototype yet — validation.csv all TBD | ❌ OPEN (expected) |
| Images | No build photos yet | ❌ OPEN (expected) |

**Overall: PACKET SHIPS as first-order design document.** 3 open items are expected pre-build; 2 degraded items are bash-availability-dependent (can be resolved by running the generate script).

---

## Gate-by-Gate Detail

### ✅ Packet structure (root-mode)

All required Mode A files are present:

| File | Required | Status |
|---|---|---|
| README.md | ✅ | ✅ Hero section, file map, build workflow, top risks |
| design.md | ✅ | ✅ Governing model, all formulas, hole table |
| bom.csv | ✅ | ✅ 11 line items |
| sourcing.csv | ✅ | ✅ 10 suppliers |
| cut-list.csv | ✅ | ✅ 4 parts with stock and finished dims |
| validation.csv | ✅ | ✅ 19 checks (all TBD — pre-build expected) |
| assembly-manual.md | ✅ | ✅ 6 stages with checkpoints |
| supplier-rfq.md | ✅ | ✅ 4 RFQ items |
| visual-bom-brief.md | ✅ | ✅ Hero spec + 9 part photos |
| drawing-brief.md | ✅ | ✅ 4 drawings specified + CAD status |
| risks.md | ✅ | ✅ 12 risks, 5 categories |
| photo-shotlist.md | ✅ | ✅ 6 phases, 20 shots |
| resources.md | ✅ | ✅ Cultural provenance, references, open items |
| jig-decision.md | ✅ | ✅ 4 jig decisions with trade-off analysis |
| wolfram/instrument-model.wl | ✅ | ✅ Full model with Manipulate |
| drawings/ (4 SVGs) | ✅ | ✅ bore-profile, tonehole-layout, embouchure, drill-setup |
| cnc/cnc-plan.json | ✅ | ✅ 9 operations, release checks |
| cnc/operations.csv | ✅ | ✅ Machine-readable operation graph |
| cnc/setup-sheet.md | ✅ | ✅ Human setup sheet |
| jigs/headstock-bore-jig.md | ✅ | ✅ Materials, fabrication, setup checklist |
| jigs/tonehole-drilling-jig.md | ✅ | ✅ Setup, stop distances table |
| cad/README.md | ✅ | ✅ Placeholder with workflow notes |
| site/index.html | ✅ | ✅ Static site with all sections |
| capstone-deck.md | ✅ | ✅ Slide outline (binary .pptx deferred) |
| print-packet.md | ✅ | ✅ Print-ready MD (binary .pdf deferred) |
| xiao-design-table.xlsx | ✅ (pre-existing) | ✅ All 26 keys × 3 variants |

---

### ✅ Physics model correctness

- **Model:** Open-open cylindrical pipe — correct for end-blown xiao
- **NAF K2 correction:** Explicitly excluded — guard rule followed
- **End correction:** 0.6·r at each end — standard Levine-Schwinger; embouchure assumption flagged as TBD
- **Tone-hole formula:** Acoustic-length first-order method — correct starting point; flagged as estimate
- **Scale offsets:** +2,+3,+4,+5,+7,+9,+10,+11 — verified against acoustic-models.md xiao row
- **Key convention:** Key = 4th hole = root + 5 semitones — verified against design table header
- **A4 sanity check:** f = 440 Hz ✅ | D4 = 293.66 Hz ✅
- **Known reference check:** G Nan Xiao L_bore ≈ 22.5 in; traditional xiao ~58–60 cm ≈ 22.8–23.6 in ✅ consistent

---

### ✅ Drawings

4 SVG drawings generated. All include title blocks, datums, critical dimensions, and first-order callouts:

| Drawing | Gate items | Status |
|---|---|---|
| xiao-bore-profile.svg | Title block, units, scale note, datum, bore ID, OD, wall, L_bore ⚠ callout | ✅ |
| xiao-tonehole-layout.svg | All 8 holes with positions, notes, hand groups, RH/LH labels | ✅ |
| xiao-embouchure-detail.svg | Cross-section + side view, notch dims TBD callout, bevel, airstream | ✅ |
| xiao-headstock-drill-setup.svg | Lathe setup, safety zone, peck annotation, anti-rotation callout | ✅ |

**Missing:** SolidWorks 3D renders (CAD not yet modeled — expected for prototype stage).

---

### ✅ CNC / operation plan

- cnc-plan.json: 9 operations with inputs, outputs, tooling, release checks ✅
- operations.csv: Machine-readable, shop-sortable ✅
- setup-sheet.md: Human setup sheet with OP-01 through OP-09 ✅
- No G-code emitted (correct — pre-CAM planning only) ✅
- Scrap-blank validation gate correctly placed before tonewood ✅

---

### ✅ Wolfram package

- `wolfram/instrument-model.wl` present ✅
- Parameters at top ✅
- `Manipulate` control with bore variant, key, and temperature sliders ✅
- Audio preview via `SoundNote` arpeggio ✅
- Validation plot: hole position vs semitone offset ✅
- `CentsError` function for post-prototype validation ✅
- `CreateDocument` entry point commented out (correct — requires Wolfram Desktop) ✅

---

### ✅ Risk register

- 12 risks across 5 categories ✅
- Each risk has a verification test ✅
- 3 HIGH risks, 5 MEDIUM risks, 4 LOW risks ✅
- Risk categories covered: acoustic, structural, ergonomic, supply, fit/finish ✅
- No risk without a test ✅

---

### ⚠ Capstone deck / print packet (DEGRADED — not blocking)

- capstone-deck.md: 12-slide outline complete ✅
- print-packet.md: Full print-ready content complete ✅
- capstone-deck.pptx: ❌ NOT GENERATED — bash workspace unavailable during packet build
- print-packet.pdf: ❌ NOT GENERATED — bash workspace unavailable

**Resolution:** Run the following when bash is available:
```bash
cd /sessions/.../mnt/GitHub/xiao
python3 /sessions/.../mnt/.claude/skills/instrument-maker-v4/scripts/generate_capstone_docs.py . --title "Xiao Capstone"
```

This is a tooling environment issue, not a design issue. The packet content is complete.

---

### ❌ CAD (OPEN — expected at prototype stage)

SolidWorks part and assembly not yet created. `cad/README.md` documents the planned workflow.

**Next action:** Generate SW design table from xiao-design-table.xlsx, then model the body part.

---

### ❌ Measured data (OPEN — pre-build)

No prototype has been built. All validation.csv rows are TBD. This is expected at the design-packet stage.

**Next action:** Build prototype → measure → populate validation.csv → run `scripts/record_measurement.py` to update the empirical-learning loop.

---

### ❌ Images (OPEN — pre-build)

No build photos. images/ folder is empty. photo-shotlist.md specifies 20 shots across 6 phases.

---

## Remaining Build Risks (summary for handoff)

These are the items a builder must resolve before the instrument ships:

1. **Order 55/64 in long-series bit** (lead time 3–5 days — order first, before cutting stock)
2. **Scrap bore validation** — bore wander must be < 0.030 in before touching tonewood
3. **Measure embouchure end correction** — blow blank after notch, before drilling holes. If fundamental error > ±15 cents vs 293.66 Hz, recalculate L_bore and update hole positions
4. **Bore finish → re-tune** — apply BLO before final voicing; BLO raises pitch 1–5 cents
5. **Undercut incrementally** — holes drilled 1–2 mm under model position; undercut to correct
6. **Generate binary capstone-deck.pptx and print-packet.pdf** — run generate_capstone_docs.py when bash available
7. **Model SolidWorks body** — from design table; optional for prototype but needed for production

---

## Verifier Sign-off

This packet is **ready for prototype build** with the first-order acoustic model as the starting point. The critical constraint is that all tuning claims are estimates — the real instrument will tell us the true end corrections and hole position corrections. The validation.csv is the instrument for capturing that data and closing the empirical loop.

**Packet version:** v4.3 root-mode  
**Validator:** instrument-maker-v4 verifier (manual)  
**Date:** 2026-05-08

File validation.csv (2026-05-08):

Check ID | Stage | Parameter | Target | Tolerance | Method | Result | Cents Error | Pass/Fail | Notes
V-BORE-SCRAP | Boring — scrap blank | Bore diameter (scrap) | 0.866 in | ±0.005 in | Drill gauge / telescoping gauge | TBD |  | TBD | Run bore validation on pine/poplar scrap BEFORE tonewood
V-BORE-WANDER | Boring — scrap blank | Bore wander (exit vs entry) | < 0.030 in | — | Measure both ends with calipers | TBD |  | TBD | Reject if wander > 1/16 in; re-jig tailstock carrier
V-BORE-TONE | Boring — tonewood | Bore diameter (walnut) | 0.866 in | ±0.005 in | Drill gauge | TBD |  | TBD | Final bore after reaming/lapping
V-BLANK-LENGTH | Turning | Blank total length | 25.5 in | +0.25 / −0 in | Steel rule / calipers | TBD |  | TBD | Leave trim allowance; do not cut short
V-OD-ROUND | Turning | OD at mid-bore | 1.338 in | ±0.010 in | Calipers | TBD |  | TBD | Turn OD round using bore axis as datum
V-EMBROCHURE | Embouchure | Notch geometry (U-notch) | TBD dimensions | — | Caliper + template | TBD |  | TBD | See drawing-brief for notch width/depth; refine by playing
V-FUND-FREQ | Tuning | Fundamental (root D4) | 293.66 Hz | ±5 cents | Strobe tuner (Korg OT-120 or Peterson) | TBD |  | TBD | All holes closed; play softly at 68°F
V-END-CORR | Tuning | Embouchure end correction vs model | 0.260 in (model) | TBD | Back-calculate from measured f_fund | TBD |  | TBD | Compute as: L_eff_measured = c/(2·f_meas); δ_emb = L_eff_measured − L_bore − δ_foot
V-HOLE1 | Tuning | Hole 1 — E4 | 329.63 Hz | ±10 cents | Strobe tuner | TBD |  | TBD | RH pinky; measure after boring hole at model position; undercut to correct
V-HOLE2 | Tuning | Hole 2 — F4 | 349.23 Hz | ±10 cents | Strobe tuner | TBD |  | TBD | RH ring
V-HOLE3 | Tuning | Hole 3 — Gb4 | 369.99 Hz | ±10 cents | Strobe tuner | TBD |  | TBD | RH middle
V-HOLE4 | Tuning | Hole 4 — G4 | 392.00 Hz | ±10 cents | Strobe tuner | TBD |  | TBD | RH index — xiao key note
V-HOLE5 | Tuning | Hole 5 — A4 | 440.00 Hz | ±10 cents | Strobe tuner | TBD |  | TBD | LH ring
V-HOLE6 | Tuning | Hole 6 — B4 | 493.88 Hz | ±10 cents | Strobe tuner | TBD |  | TBD | LH middle
V-HOLE7 | Tuning | Hole 7 — C5 | 523.25 Hz | ±10 cents | Strobe tuner | TBD |  | TBD | LH index
V-HOLE8 | Tuning | Hole 8 — Db5 | 554.37 Hz | ±10 cents | Strobe tuner | TBD |  | TBD | LH thumb
V-OCTAVE | Tuning | Overblown octave (hole 5 overblow → A5) | 880.00 Hz | ±15 cents | Strobe tuner | TBD |  | TBD | Verify overblowing response; cylindrical bore should overblow at 2:1
V-BORE-FIN | Finishing | Internal bore finish applied | BLO or shellac | — | Visual + dry time | TBD |  | TBD | Apply before final tuning; finish changes effective bore and may shift pitch
V-STRUCT | Structural | No cracks at notch or holes | No visible cracks | — | Visual inspection + tap test | TBD |  | TBD | Inspect after embouchure notch cut; tap along body for dead spots

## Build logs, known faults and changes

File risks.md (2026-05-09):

# Xiao — Risk Register

**Project:** XIAO-001 · G Nan Xiao  
**Date:** 2026-05-08  
**Specialist:** Red-team walk  
**Severity:** High / Medium / Low

Every risk has a verification test. No risk is listed without a test.

---

## Acoustic Risks

### RISK-A01 — Embouchure end correction: model vs reality (HIGH)

**Description:** The first-order model assumes the U-notch embouchure behaves as a simple open end (δ_emb ≈ 0.6·r = 0.260 in). In practice the jet–edge interaction, lip coverage, and notch geometry all modulate the effective acoustic length. If the real end correction differs significantly from the model, the bore length L_bore will be wrong and all tone-hole positions will be systematically off.

**Consequence:** Fundamental frequency error of 10–30 cents; all holes require repositioning.

**Mitigation:** Leave +0.25 in trim allowance on the blank. Drill all tone holes under-length (1–2 mm toward foot). Measure fundamental before drilling holes; compute actual δ_emb = L_eff_measured − L_bore − δ_foot and update design.md.

**Verification test:** After embouchure cut but before tone holes, blow the blank and record the fundamental with a strobe tuner. Compare measured frequency to model prediction (293.66 Hz). Compute cents error. If error > ±15 cents, recalculate L_bore and update hole positions before drilling.

---

### RISK-A02 — Chromatic scale coverage gaps (MEDIUM)

**Description:** The 8-hole layout (+2,+3,+4,+5,+7,+9,+10,+11) does not cover semitones +1, +6, +8, or the octave (+12) by simple hole-open technique. These notes require cross-fingering, half-holing, or overblowing. Cross-fingerings on a short-scale instrument may yield poor intonation or tone quality.

**Consequence:** Instrument is not fully chromatic by simple fingering; some passages require advanced technique.

**Mitigation:** Document the fingering chart explicitly. Test cross-fingerings on the prototype and note cents errors. Consider whether +1 (m2) requires a vent hole (as on some modern xiao).

**Verification test:** After voicing, play all 12 chromatic semitones of the first octave using standard xiao fingerings. Record cents error for each cross-fingered note. Accept if ≤ ±20 cents (playable with embouchure correction); flag if > ±20 cents.

---

### RISK-A03 — Bore finish shifts tuning (MEDIUM)

**Description:** Internal bore finish (BLO, shellac, lacquer) reduces the effective bore diameter and raises the fundamental pitch. The magnitude depends on film thickness and material. Applying finish after voicing will sharpen all notes unpredictably.

**Consequence:** Holes need re-voicing after finish. If finish is too thick, notes may be irrecoverably sharp.

**Mitigation:** Apply bore finish before final voicing (as specified in assembly-manual.md Stage 6). Allow full cure before tuning. Note: BLO raises pitch ~1–3 cents; shellac may raise ~3–8 cents. Mark these as TBD assumptions in validation.csv.

**Verification test:** Measure fundamental before and after bore finish application. Record ΔHz and Δcents. Update validation.csv row V-BORE-FIN.

---

### RISK-A04 — Temperature sensitivity during tuning (LOW)

**Description:** Speed of sound changes ~0.6 m/s per °C (≈ 1 cent per °F in this bore range). If the instrument is tuned in a cold shop and played in a warm room, it will play sharp.

**Consequence:** Pitch drift of ~5–10 cents between cold shop and warm performance space.

**Mitigation:** Tune at 68°F. Note tuning temperature in validation.csv. Advise player to warm instrument before playing (blow through for 2–3 minutes).

**Verification test:** Record room temperature at every tuning session. Compare fundamental at 60°F vs 75°F if both conditions are available during build.

---

## Structural Risks

### RISK-S01 — Bore wander causing eccentric wall (HIGH)

**Description:** A 22.5 in bore through 1.5 in square stock is at the limit of practical straight-bore drilling. If the bit wanders, the wall thickness will be uneven. A thin wall (<1/8 in) at any point may crack under playing stress or during final turning.

**Consequence:** Structural failure of body; wasted tonewood blank.

**Mitigation:** Scrap-blank validation before drilling tonewood (per assembly-manual.md Stage 2). Rigid tailstock carrier with anti-rotation feature. Peck drilling with chip clearing. Step through intermediate bit sizes.

**Verification test (V-BORE-WANDER):** On scrap blank, measure bore entry center vs bore exit center. Wander must be < 0.030 in (less than half wall thickness for minimum 0.118 in Qin Xiao wall). Reject and re-jig if exceeded.

---

### RISK-S02 — Embouchure notch cracks at wall (HIGH)

**Description:** The U-notch removes material from the thin upper wall of the mouthpiece section, creating a stress concentration. Black walnut is strong but the notch introduces a hard corner at the bore tangent line. Cracks may initiate here under the cycling stress of repeated playing.

**Consequence:** Structural crack propagates along grain; instrument unusable.

**Mitigation:** Keep notch width ≤ 12 mm (do not exceed bore diameter). Radius the notch corners (avoid sharp square cuts). Seal grain at notch immediately after cutting (thin CA glue or shellac). Inspect after 5 playing sessions.

**Verification test (V-STRUCT):** Visual inspection with loupe after embouchure cut. No grain separation or cracks visible at notch corners. Tap test: body should ring cleanly, not produce a dead thud.

---

### RISK-S03 — Tone hole undermining wall integrity (MEDIUM)

**Description:** Eight holes drilled through a 0.236 in wall — if any hole is off-axis or oversized, the through-wall remaining material may be dangerously thin at the bore tangent.

**Consequence:** Hole-edge splitting or crack between adjacent holes.

**Mitigation:** Use pilot bit before finish bit. Keep hole diameter ≤ 10 mm on front holes (wall clearance = 0.236 in − hole_radius_projected). Minimum spacing between holes: hole diameter + 2 × wall thickness.

**Verification test:** After each hole, inspect bore interior (mirror or flashlight through foot) for any visible wall penetration beyond the intended hole footprint. No cracks or splits visible.

---

## Ergonomic Risks

### RISK-E01 — Hole spacing vs hand span (MEDIUM)

**Description:** The first-order hole positions (holes 1–8 at 20.48 to 12.18 in from foot) produce a hole group spanning about 8.3 in. This is within the reach of most adult hands but may be uncomfortable for players with smaller hands, particularly the span from hole 4 (RH index) to hole 5 (LH ring) — a gap of approximately 1.88 in (47.8 mm).

**Consequence:** Instrument may be difficult or impossible for players with hand spans below ~17 cm.

**Mitigation:** This is the traditional xiao geometry — the hand span requirement is intrinsic to the key. Note the minimum hand span in documentation. For accessibility, a smaller key (higher pitch) can be used — the design table covers all 26 keys.

**Verification test:** Measure the actual hole 4-to-hole 5 center distance on the finished instrument. Compare to ergonomic database: 5th-percentile female adult hand span ≈ 175 mm; the gap should be ≤ 50 mm for comfortable reach. Record in validation.csv.

---

### RISK-E02 — Playing angle and embouchure fatigue (LOW)

**Description:** The xiao is held at approximately 45° from vertical (angled toward player) or near-vertical. The embouchure requires more lip control than a transverse flute. Beginners commonly find the instrument difficult to produce a tone from initially.

**Consequence:** Not a build risk, but a documentation risk — the instrument should be clearly labeled as requiring technique to produce a tone.

**Mitigation:** Include embouchure setup notes in assembly-manual.md. Recommend 30-minute sustained practice sessions over multiple days before concluding that the instrument is defective.

**Verification test:** Any person familiar with end-blown flutes can produce a stable tone on the finished instrument within 2–3 minutes. If no one can produce a tone, inspect embouchure geometry (notch width, inner bevel angle).

---

## Supply Risks

### RISK-SU01 — Long-series drill bit availability (MEDIUM)

**Description:** 55/64 in bits in 18+ in overall length are not stocked at every supplier. McMaster-Carr carries these but lead time may be 3–5 days.

**Consequence:** Build is blocked waiting for bits.

**Mitigation:** Order bits before cutting stock. Verify McMaster-Carr availability before any other procurement. Alternative: use 7/8 in (0.875 in) as finish bit and lap down — this avoids the 55/64 in odd size.

**Verification test:** Confirm bit is in hand before cutting the blank.

---

### RISK-SU02 — Walnut blank grain straightness (MEDIUM)

**Description:** A 26 in walnut blank with interlocked or irregular grain may tear during turning or produce a wandering bore if grain causes bit deflection during drilling.

**Consequence:** Unusable blank; wasted time and material.

**Mitigation:** Inspect grain direction before purchase. Prefer riftsawn or quartersawn stock. Reject blanks with visible runout > 5° from long axis. Buy a spare blank.

**Verification test:** Sight down blank before drilling. Grain should run within ~5° of the long axis for 90% of the blank length.

---

## Fit and Finish Risks

### RISK-FF01 — Bore finish pooling in tone holes (LOW)

**Description:** If BLO or shellac is applied after tone holes are drilled, finish may pool in the holes and partially obstruct them, sharpening the affected notes.

**Consequence:** Notes are sharp after finishing; difficult to correct without re-voicing.

**Mitigation:** Apply bore finish before drilling tone holes, OR mask tone holes with tape during finishing, OR apply finish sparingly with a cloth strip (not flooding).

**Verification test:** After bore finishing, sight through each tone hole (when drilled). Hole bore should be clean, no pooled finish visible. Probe with a toothpick if uncertain.

---

### RISK-FF02 — Mouthpiece section surface checks (LOW)

**Description:** Walnut can develop hairline checks (end-grain cracks) in the mouthpiece section if the wood is not fully stabilized. These checks can appear days after cutting, particularly in a dry shop.

**Consequence:** Cosmetic defect; potential crack propagation to notch zone.

**Mitigation:** Use kiln-dried (MC ≤ 8%) stock. Stabilize endgrain immediately after cutting with thin CA or shellac. Keep instrument in a moderate-humidity environment (40–50% RH) during build.

**Verification test:** Inspect mouthpiece end-grain face at 48 hr after cutting and again at 1 week. No new checks visible under 10× loupe.

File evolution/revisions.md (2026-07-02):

# Revision Register — xiao

| Rev | Date | Parent | Delta | Downstream artifacts invalidated |
| --- | --- | --- | --- | --- |
| A | 2026-07-01 | — | Stage 0 intake of current masters (cad/xiao.scad + xiao-design-table.xlsx). | none (no alpha/beta/production artifacts exist yet) |

Stage 0 only. Gate A has not been run; no Alpha compiles, vendor quotes, or production lock exist for this product.

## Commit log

2026-05-02 Initial scaffold: Xiao Family
    [xiao-design-table.xlsx]
2026-05-29 [xiao] V5 uplift: visual-output-register, mcp-session-log, family-spec, L2 status (Refs #1) (#4)
    Add visual-output-register.csv registering 4 drawings/ SVGs as derived_preview and
    wolfram/ sources as pending_measurement. Add cad/mcp-session-log.md (no external tool
    sessions). Add family-spec.csv L2 scaffold for Bei/Nan/Qin Xiao family members.
    Replace non-standard xiao status warning with V5 "Status: L2 V5 build-packet candidate".
    Refs #1
    [family-spec.csv, visual-output-register.csv]
2026-05-31 Add image-gen concept prompt; wire explorer images
2026-06-21 Wire 1 rendered concept image(s) into explorer gallery
2026-07-02 V5 packet refresh: status line, provenance, parametric OpenSCAD master, evolution intake
    - Fixed broken-bold README status line (**Status: ... ** -> **Status:** ...);
    no readiness-level change (still L2 V5 build-packet candidate).
    - Authored cad/xiao.scad: new parametric OpenSCAD master scoped to bore +
    tone-hole array only (blowing-edge notch explicitly out of scope). Hole
    positions and L_eff/L_bore derived by formula from design.md 2.3/2.4/2.6
    and cross-checked exactly against design.md's published table via
    OpenSCAD echo output. Flags a bore_id/wall_thickness discrepancy between
    design.md's worked Nan Xiao table and the live xiao-design-table.xlsx
    row16/17 column E cells (do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
    [visual-output-register.csv, xiao.scad]
